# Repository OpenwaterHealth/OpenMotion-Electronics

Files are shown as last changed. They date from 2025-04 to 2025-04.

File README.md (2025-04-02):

# OpenMotion-Electronics
This repository contains the electrical layout files for all of the PCBs required for OpenMotion

# Overview
Electrical files for OpenMotion will be uploaded when major releases occur.

OpenMotion is still in development and files here represent prototypes for the three PCBAs required for OpenMotion. Those are: the console board, the camera aggregator board, and the camera sensor board. Eight camera sensor boards connect to a single camera aggregator board. Each aggregator connects to the console board via a 10 pin cable. Two aggregator boards (more broadly, sensor modules), may be connected to the console at a time. The console contains power conditioning electronics, laser control electronics, and components for connecting the two aggregator boards to the host PC. A power supply provides 12V to the Console Board. The console board connects to the host via USB Type-C.

Please see the other repositories in this organization for the Mechanical and Software files.

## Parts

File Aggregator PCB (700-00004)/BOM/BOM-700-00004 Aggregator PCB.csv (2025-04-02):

Line # | Name | Description | Designator | Revision ID | Revision Status | Quantity | TargetPrice | JLCPCB Part # | Manufacturer 1 | Manufacturer Part Number 1 | Manufacturer Lifecycle 1 | Supplier 1 | Supplier Part Number 1 | Supplier Unit Price 1 | Supplier Subtotal 1
 | 100nf | Cap Ceramic 100nF 10V X7R ±10% SMD 0402 +125°C Paper T/R | C6, C23, C24, C25, C26, C28, C34, C35, C36, C39 | CMP-13271-001069-1 | Up to date | 10 | 0 | C133086 | Samsung | CL05B104KP5NNNC | Volume Production | Digikey | 1276-1002-6-ND | 0.004 | 0.4
 | 2.2uF | CAP CER 2.2UF 10V X5R 0402 | C31, C32, C37 | CMP-03422-000618-1 | Up to date | 3 | 0 | C326606 | Yageo | CC0402KRX5R6BB225 | Volume Production | Digikey | 311-1686-1-ND | 0.053 | 1.59
 | BM10B-SURS-TF(LF)(SN) | CONN HEADER SMD 10POS 0.8MM | J9 | CMP-17439-000608-1 | Up to date | 1 | 0 | C5306166 | JST | BM10B-SURS-TF(LF)(SN) | Unknown
 | U.FL-R-SMT(10) | Ultra Small Surface Mount Coaxial Connector, 50 Ohm, -40 to 90 degC, 3-Pin SMD, RoHS, Tape and Reel | SYNC | CMP-002-00035-2 | Up to date | 1 | 0 | C5137195 | Hirose | U.FL-R-SMT(10) | Volume Production | Digikey | H9161DKR-ND | 0.975 | 9.75
 | QBLP595-IG | Chip LED 0402, Green, 0.02 A, 3.1 to 3.7 V, -40 to 80 degC, 2-Pin SMD, RoHS, Tape and Reel | V3 | CMP-007-00041-3 | Up to date | 1 | 0 | C264408 | QT-Brightek | QBLP595-IG | Unknown | Digikey | 1516-1216-6-ND | 0.181 | 1.81
 | QBLP595-R | Chip LED 0402, Red, 0.02 A, 2.0 to 2.5 V, -40 to 80 degC, 2-Pin SMD, RoHS, Tape and Reel | ERR | CMP-007-00040-3 | Up to date | 1 | 0 | C71911 | QT-Brightek | QBLP595-R | Unknown | Digikey | 1516-1217-6-ND | 0.167 | 1.67
 | 27K |  | R1 | CMP-2002-07025-1 | Up to date | 1 | 0 | C138022 | Yageo | RC0402FR-0727KL | Volume Production | Digikey | 311-27.0KLRCT-ND | 0.008 | 0.08
 | 10K |  | R2, R4, R5, R24, R25, R26, R36, R38 | CMP-2002-07353-1 | Up to date | 8 | 0 | C60490 | Yageo | RC0402FR-0710KL | Volume Production | Digikey | 311-10.0KLRDKR-ND | 0.0081 | 0.81
 | 56K |  | R3 | CMP-1011-00708-2 | Up to date | 1 | 0 | C114756 | Yageo | RC0402FR-0756KL | Volume Production | Digikey | 311-56.0KLRCT-ND | 0.007 | 0.07
 | 2.2K |  | R8, R9, R10, R11, R12, R13, R14, R15, R16, R17, R18, R19, R20, R21, R22, R23 | CMP-2002-07567-1 | Up to date | 16 | 0 | C114762 | Yageo | RC0402FR-072K2L | Volume Production | Digikey | 311-2.20KLRDKR-ND | 0.0071 | 1.136
 | 270 |  | R33, R34 | CMP-2002-07003-1 | Up to date | 2 | 0 | C163474 | Yageo | RC0402FR-07270RL | Volume Production | Digikey | 311-270LRDKR-ND | 0.007 | 0.14
 | ST1L05BPUR | Very Low Quiescent BiCMOS Voltage Regulator, Adjustable Vo, 6-Pin VFDFPN, Tape and Reel | U1 | CMP-0244-00292-1 | Up to date | 1 | 0 | C155640 | STMicroelectronics | ST1L05BPUR | Volume Production | Digikey | 497-6829-1-ND | 0.731 | 7.31
 | ST1L05CPU33R | Very Low Quiescent BiCMOS Voltage Regulator, 3.3V, 6-Pin VFDFPN, Tape and Reel | U3, U6 | CMP-0244-00293-1 | Up to date | 2 | 0 | C2969933 | STMicroelectronics | ST1L05CPU33R | Volume Production | Digikey | 497-10617-1-ND | 0.731 | 14.62
 | ICM-20948 | World’s Lowest Power 9-Axis MEMS MotionTracking(TM) Device, 1.71 to 3.6 V, -40 to 85 degC, 24-Pin QFN, RoHS, Tape and Reel | U5 | CMP-2000-07532-1 | Up to date | 1 | 0 | C726001 | TDK | ICM-20948 | Unknown
 | 5.1k |  | R31, R32 | CMP-2002-07753-1 | Up to date | 2 | 0 | C105872 | Yageo | RC0402FR-075K1L | Volume Production | Digikey | 311-5.10KLRDKR-ND | 0.008 | 0.16
 | 4.7uF | CAP CER 4.7UF 10V X5R 0402 | C1, C2, C3, C4, C10, C11, C12, C13, C14, C15, C16, C17, C18, C19, C27, C30 | CMP-2000-05997-2 | Up to date | 16 | 0 | C82864 | TDK | C1005X5R1A475K050BC | Volume Production | Digikey | 445-13820-6-ND | 0.098 | 15.68
 | 100nF | Chip Multilayer Ceramic Capacitors for General Purpose, 0402, 0.10uF, X7R, 15%, 10%, 50V | C5, C8, C9 | CMP-2008-04639-2 | Up to date | 3 | 0 | C77020 | Murata | GRM155R71H104KE14D | Volume Production | Digikey | 490-10700-6-ND | 0.023 | 0.69
 | Capacitor 1 uF +/- 10% 6.3 V 0402 | Chip Capacitor, 1 uF, +/- 10%, 6.3 V, 0402 (1005 Metric) | C7, C29, C33, C38 | CMP-001-00008-6 | Up to date | 4 | 0 | C14445 | Kyocera AVX | 04026D105KAT2A | Volume Production | Digikey | 478-KGM05AR50J105KHCT-ND | 0.017 | 0.68
 | 6pF | Multi-Layer Ceramic Capacitor 6pF C0G ±0.25pF 0402 Paper T/R | C21, C22 | CMP-2008-03869-2 | Up to date | 2 | 0 | C161330 | Murata | GJM1555C1H6R0CB01D | Volume Production | Digikey | 490-3104-1-ND | 0.036 | 0.72
 | 1-2328702-0 | No Description Available | J1, J2, J3, J4, J5, J6, J7, J8 |  |  | 8 | 0 | C3167956
 | 2.2k |  | R6, R7 | CMP-2002-07517-1 | Up to date | 2 | 0 | C82868 | Yageo | RC0402FR-0722KL | Volume Production
 | 8.06K |  | R37 | CMP-2002-07081-1 | Up to date | 1 | 0 | C276278 | Yageo | RC0402FR-078K06L | Volume Production | Digikey | 311-8.06KLRDKR-ND | 0.008 | 0.08
 | STM32H743VIH6 | HIGH-PERFORMANCE AND DSP WITH DP | U2 | CMP-12105-000020-1 | Up to date | 1 | 0 | C964146 | STMicroelectronics | STM32H743VIH6 | Volume Production | Digikey | 497-STM32H743VIH6-ND | 12.814 | 128.14
 | TCA9548ARGERQ1 | IC BUS SWITCH 1 X 8:1 24VQFN | U4 | CMP-04892-000080-1 | Up to date | 1 | 0 | C2674697 | Texas Instruments | TCA9548ARGERQ1 | Volume Production | Digikey | 296-TCA9548ARGERQ1CT-ND | 1.537 | 15.37
 | USB3320C-EZK-TR | IC TRANSCEIVER HALF 1/1 32QFN | U7 | CMP-0186-00336-2 | Up to date | 1 | 0 | C132156 | Microchip | USB3320C-EZK-TR | Volume Production | Digikey | USB3320C-EZK-DKR-ND | 2.17 | 21.7
 | 24MHz | CRYSTAL 24.0000MHZ 6PF SMD | Y1 | CMP-06054-000017-1 | Up to date | 1 | 0 | C127895 | Murata | XRCGB24M000F3M00R0 | Volume Production | Digikey | 490-5576-1-ND | 0.269 | 2.69
 | EVP-AWED4A | Tactile Switch SPST-NO Top Actuated Surface Mount | RST | CMP-050-000000-1 | Up to date | 1 | 0 | C585166
 | Resistor 4K7 +/-1 % 0402 63 mW | Chip Resistor, 4,7 kOhms, +/-1 %, 63 mW, -55 to 155 degC, 0402 | R27, R28, R29, R30, R35, R39, R40, R41 | CMP-009-00158-3 | Up to date | 8 | 0 | C25900 | Bourns | CR0402-FX-4701GLF | Volume Production | Digikey | CR0402-FX-4701GLFDKR-ND | 0.0063 | 0.63
 | SN74LV1T125DBVR | Single Power Supply, Single BUFFER GATE w/ 3-State Output (active low enable), DBV0005A, LARGE T&R | U8, U9 | CMP-0859-00122-3 | Up to date | 2 | 0 | C473338 | Texas Instruments | SN74LV1T125DBVR | Volume Production | Digikey | 296-37172-6-ND | 0.265 | 5.3

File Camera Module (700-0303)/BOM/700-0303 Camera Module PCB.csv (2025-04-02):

Line # | Name | Description | Designator | Revision Status | Quantity | Footprint | Manufacturer 1 | Manufacturer Part Number 1 | Manufacturer Lifecycle 1 | Supplier 1 | Supplier Part Number 1 | Supplier Subtotal 1
 | 4.7uF | Capacitor,4.7µF ±10% 6.3V Ceramic Capacitor X5R 0201 (0603 Metric) | C1 |  | 1 | CAP_CC0201_YAG
 | 1uF | Capacitor,1 µF ±10% 6.3V Ceramic Capacitor X5R 0201 (0603 Metric) | C2, C3, C4, C5, C6, C9, C10 |  | 7 | CAP_CC0201_YAG
 | 0.1uF | CAP,0.1µF ±10% 6.3V Ceramic Capacitor X5R 0201 (0603 Metric) | C7, C11, C12, C17, C18, C19, C20, C21 |  | 8 | CAP_CC0201_YAG
 | 2.2uF | CAP,2.2µF ±10% 6.3V Ceramic Capacitor X5R 0201 (0603 Metric) | C8, C13, C14, C15, C16 |  | 5 | CAP_CC0201_YAG
 | 10K | RES, 10 kOhms Â±1% 0.05W, 1/20W Chip Resistor 0201 _0603 Metric_ Thick Film | R1, R7 |  | 2 | RESC0603X28N
 | 20K | RES, 20 kOhms Â±1% 0.05W, 1/20W Chip Resistor 0201 _0603 Metric_ Thick Film | R2 |  | 1 | RESC0603X28N
 | 30K | RES, 30 kOhms Â±1% 0.05W, 1/20W Chip Resistor 0201 _0603 Metric_ Thick Film | R3 |  | 1 | RESC0603X28N
 | DNP | RES, 100 kOhms Â±1% 0.05W, 1/20W Chip Resistor 0201 _0603 Metric_ Thick Film | R6 |  | 1 | RESC0603X28N
 | 100K | RES, 100 kOhms Â±1% 0.05W, 1/20W Chip Resistor 0201 _0603 Metric_ Thick Film | R8 |  | 1 | RESC0603X28N
 | MIC5335-JGYMT-TR | IC, Linear Voltage Regulator IC Positive Fixed 2 Output 300mA, 300mA 6-TMLF® (1.6x1.6) | U1 |  | 1 | TMLF-6_MT_MCH
 | LIF-MD6000-6UWG36ITR | IC, FPGA - Field Programmable Gate Array Crosslink Interface MIPI D-Phy Bridge | U2 |  | 1 | BGA36N40P6X6_248X254X57N
 | 0X02C1B | IC, Camersa Sensor | U3 |  | 1 | OV_CSP-56
 | NCP156ABFCT120280T2G | IC, LDO Voltage Regulators DUAL 500 MA / 250 M A LDO | U4 |  | 1 | NCP156
 | 10K | RES, 10 kOhms Â±1% 0.05W, 1/20W Chip Resistor 0201 _0603 Metric_ Thick Film | R9 |  | 1 | RESC0603X28N
 | ECS-1618-480-BN-TR | 48MHz XO (Standard) CMOS Oscillator 1.8V Enable/Disable 4-SMD, No Lead | Y1 |  | 1 | OSC_ECS-1633-480-BN-TR
 | flex tail | Connector,10 Position FFC, FPC Connector Contacts, Bottom 0.020" (0.50mm) Surface Mount, Right Angle | J1 |  | 1 | flex tail
 | DNP | RES, 10 kOhms Â±1% 0.05W, 1/20W Chip Resistor 0201 _0603 Metric_ Thick Film | R10 |  | 1 | RESC0603X28N

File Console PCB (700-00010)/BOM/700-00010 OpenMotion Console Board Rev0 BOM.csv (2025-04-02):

Line # | Name | Description | Designator | Revision Status | Quantity | Footprint | Manufacturer 1 | Manufacturer Part Number 1 | Manufacturer Lifecycle 1 | Supplier 1 | Supplier Part Number 1 | Supplier Subtotal 1
 | 4.7uF | Capacitor, 4.7 µF ±10% 35V Ceramic Capacitor X5R 0805 (2012 Metric) | C53, C57 |  | 2 | CAPC2012X135N
 | 47uF | Capacitor,47 µF ±10% 16V Ceramic Capacitor X5R 1210 (3225 Metric) | C21, C23, C24, C27, C28, C34, C36, C360, C361, C362, C369, C370, C371, C372, C373, C374, C375 |  | 17 | CAP_CL32_SAM
 | 22uF | Capacitor, 22 µF ±20% 10V Ceramic Capacitor X5R 0805 (2012 Metric) | C178, C184, C193, C402, C408, C417, C458, C464, C473 |  | 9 | CAPC2012X140N
 | 0.1uF | CAP, 0.1 µF ±10% 25V Ceramic Capacitor X5R 0402 (1005 Metric) | C8, C11, C13, C14, C16, C22, C25, C30, C31, C32, C33, C35, C38, C39, C47, C48, C55, C61, C63, C65, C80, C88, C90, C91, C95, C96, C97, C100, C103, C104, C106, C108, C112, C130, C131, C132, C134, C137, C141, C142, C143, C146, C147, C158, C160, C161, C162, C163, C164, C167, C168, C173, C175, C179, C182, C183, C185, C187, C191, C192, C195, C196, C200, C202, C205, C207, C208, C210, C215, C218, C220, C221, C223, C229, C230, C232, C233, C234, C235, C237, C238, C239, C240, C242, C243, C244, C245, C246, C249, C250, C251, C252, C286, C310, C313, C315, C316, C317, C319, C320, C321, C322, C324, C326, C329, C330, C332, C334, C339, C342, C343, C344, C345, C346, C350, C355, C359, C366, C376, C381, C383, C391, C392, C397, C398, C399, C403, C406, C407, C409, C411, C415, C416, C419, C420, C437, C438, C443, C447, C448, C453, C455, C459, C462, C463, C465, C467, C471, C472, C475, C477, C480, C481, C525, C528, C532, C533, C534, C535, C536, C537, C538, C539, C540, C541, C542, C544, C545, C546, C547, C549, C550, C553, C554, C555, C556, C558 |  | 177 | G-155_MUR
 | 1uF | CAP, 1µF ±10% 25V Ceramic Capacitor X5R 0402 (1005 Metric) | C20, C43, C52, C85, C99, C109, C111, C204, C384, C504, C510, C513, C515 |  | 13 | G-155_MUR
 | 22uF | CAP, 22 µF ±20% 25V Ceramic Capacitor X5S 0603 (1608 Metric | C180, C189, C198, C404, C413, C422, C460, C469, C478 |  | 9 | CAPC17795_95N_KEM
 | 10uF | CAP, 10 µF ±20% 16V Ceramic Capacitor X5R 0603 (1608 Metric) | C113, C118, C120, C122, C172, C209, C211, C222, C224, C231, C236, C248, C314, C318, C358, C516, C529, C530, C531, C543, C548, C551 |  | 22 | CAP_GRM188_MUR
 | 0.1uF | CAP, 0.1 µF ±10% 25V Ceramic Capacitor X5R 0402 (1005 Metric) | C58, C72, C107, C385, C386 |  | 5 | G-155_MUR
 | 0.1uF | CAP, 0.1upF ±10% 200V Ceramic Capacitor X7R 0603 (1608 Metric) | C156 |  | 1 | CAPC17795_95N_KEM
 | 4.7uF | CAP, 4.7 µF ±20% 16V Ceramic Capacitor X5R 0402 (1005 Metric) | C102 |  | 1 | CAP_CC0402_YAG | Murata | GRM155R62A104ME14D | Volume Production | Arrow Electronics | GRM155R62A104ME14D | 74
 | APT1608SURCK | LED, Red 630nm LED Indication - Discrete 1.95V 0603 (1608 Metric) | D1, D5, D17 |  | 3 | LED_APT1608_KNB
 | GRN | LED, Green 570nm LED Indication - Discrete 2V 0402 (1005 Metric) | D14, D19, D20, D21, D44, D45, D55, D62, D63, D64 |  | 10 | FP-SML-P11MTT86R_0402-MFG
 | VLMO1500-GS08 | LED, Blue 470nm LED Indication - Discrete 2.7V 0402 (1005 Metric) | D13, D18 |  | 2 | FP-SML-P11MTT86R_0402-MFG
 | 5.5A TRIP | FUSE, Polymeric PTC Resettable Fuse 24V 3.3 A Ih Surface Mount 2920 (7351 Metric), Concave | F2 |  | 1 | 0ZCF0330FF2C_BEL
 | 25 Ohm @ 6A | Ferrite Bead, 25 Ohms @ 100 MHz 1 Power Line Ferrite Bead 0805 (2012 Metric) 6A 4mOhm | FB2, FB17 |  | 2 | IND_FBMJ-08052012_TAY
 | 30 Ohms 3A | Ferrite Bead, 30 Ohms 1 Signal Line Ferrite Bead 0603 (1608 Metric) 3A 40mOhm | FB1, FB3, FB4, FB5, FB6, FB7, FB8, FB9, FB10, FB11, FB12, FB13, FB14, FB15, FB16, FB18, FB19, FB20, FB21, FB22, FB23, FB24, FB25, FB26, FB27, FB28, FB33, FB34, FB35, FB36, FB37, FB39, FB57, FB58, FB59, FB60 |  | 36 | WE-CBF-0603
 | 120 Ohm | Ferrite Bead , 120 Ohms 1 Power Line 0402 (1005 Metric) 2A 55mOhm | FB31, FB32, FB45, FB46, FB51, FB52, FB53, FB54, FB55 |  | 9 | IND_BLM15_0402_MUR
 | CSD15380F3T | MOSFET, 20-V N-Channel FemtoFET MOSFET 3-PICOSTAR -55 to 150 | Q13, Q15 |  | 2 | TRXDFN69X60X35-3N
 | 10K | Resistor, 10K Ohms ±1% 0.063W, 1/16W Chip Resistor 0402 (1005 Metric) Moisture Resistant Thick Film | R2, R44, R95, R112, R115, R116, R118, R121, R125, R128, R129, R131, R134, R141, R150, R151, R152, R170, R214 |  | 19 | RC0402N_YAG
 | 4.7K | Resistor, 4.7K Ohms ±1% 0.063W, 1/16W Chip Resistor 0402 (1005 Metric) Moisture Resistant Thick Film | R40, R41, R142, R143, R165, R166 |  | 6 | RC0402N_YAG
 | 10K | RES, 10K ±1% 0.063W, 1/16W Chip Resistor 0402 (1005 Metric) Thick Film | R299, R308 |  | 2 | BO_CR0402
 | 10K Ohm | Resistor, 10K Ohms ±1% 0.063W, 1/16W Chip Resistor 0402 (1005 Metric) Moisture Resistant Thick Film | R3, R31, R35, R49, R85, R100, R113, R326, R328, R342, R344 |  | 11 | RC0402N_YAG
 | 29.4K | Resistor, 29.4 kOhms ±1% 0.063W, 1/16W Chip Resistor 0402 (1005 Metric) Automotive AEC-Q200 Thick Film | R13 |  | 1 | STA_RMCF0402_STP
 | 35mOhm | Resistor, 35 mOhms ±1% 1W Chip Resistor 2512 (6432 Metric) Automotive AEC-Q200, Current Sense, Moisture Resistant Metal Element | R271, R283 |  | 2 | RESC6432X80N
 | 10K Ohm | Resistor, 10K Ohms ±1% 0.063W, 1/16W Chip Resistor 0402 (1005 Metric) Moisture Resistant Thick Film | R5, R6, R15, R28, R34, R68, R70, R80, R83, R88, R89, R97, R103, R108, R110, R242, R249, R261, R265, R293, R302 |  | 21 | RC0402N_YAG
 | 86.6K | Resistor, 86.6 kOhms ±0.1% 0.063W, 1/16W Chip Resistor 0402 (1005 Metric) Automotive AEC-Q200 Thin Film | R55, R106, R206, R250, R296, R305 |  | 6 | 0402 | Yageo | RT0402FRE07100RL | Volume Production | Future Electronics | 4303467 | 29
 | 4.99K | Resistor,4.99 kOhms ±1% 0.1W, 1/10W Chip Resistor 0402 (1005 Metric) Automotive AEC-Q200 Thick Film | R58, R332, R350 |  | 3 | RC0402N_PAN
 | 24K | Resistor, 24 kOhms ±1% 0.063W, 1/16W Chip Resistor 0402 (1005 Metric) Thick Film | R56 |  | 1 | RESC1005X35N
 | 31.6K | Resistor, 31.6K Ohms ±1% 0.063W, 1/16W Chip Resistor 0402 (1005 Metric) Moisture Resistant Thick Film | R298, R307 |  | 2 | RC0402N_YAG
 | 49.9 | Resistor, 49.9 Ohms ±1% 0.063W, 1/16W Chip Resistor 0402 (1005 Metric) Moisture Resistant Thick Film | R17, R21, R76, R92, R98, R99, R203, R204, R205 |  | 9 | RC0402N_YAG
 | 24.9 | Resistor, 24.9 Ohms ±1% 0.063W, 1/16W Chip Resistor 0402 (1005 Metric) Automotive AEC-Q200 Thick Film | R36, R62, R75, R77, R94 |  | 5 | RES_CRCW_0402
 | 1.8K | Resistor, 1.8K Ohms ±1% 0.063W, 1/16W Chip Resistor 0402 (1005 Metric) Moisture Resistant Thick Film | R90 |  | 1 | RC0402N_YAG
 | 5003 | Test Point, Orange, Height 4.6 mm, Tail Length 3 mm, 1-Pin THD, RoHS | TP1, TP2, TP3, TP4, TP5, TP6, TP7, TP11, TP12, TP13, TP14, TP15, TP16, TP17, TP18, TP19, TP20, TP21, TP22, TP23, TP24, TP25, TP26, TP27, TP28, TP29, TP32, TP33, TP35, TP36, TP39, TP40 |  | 32 | KSTN-5003
 | MIC29502WU-TR | IC, Linear Voltage Regulator IC Positive Adjustable 1 Output 5A TO-263-5 | U82, U83 |  | 2 | TO-263-5_MCH
 | LTM8074EY#PBF | IC, Non-Isolated PoL Module DC DC Converter 1 Output 0.8 ~ 12V 1.2A 3.2V - 40V Input | U3, U28, U73 |  | 3 | 05-08-1566_ADI
 | LT1965IDD#PBF | IC, Linear Voltage Regulator IC Positive Adjustable 1 Output 1.1A 8-DFN (3x3) | U86, U92 |  | 2 | DFN-8_DD_LIT
 | MAX31875R2TZS+T | IC,Temperature Sensor Digital, Local -40°C ~ 125°C 12 b 4-WLP (0.84x0.84) | U13, U48, U51 |  | 3 | 21-100151A_Z40C0+2_MXM
 | LTC1440IDDPBF | Comparator with Voltage Reference CMOS, TTL 8-DFN (3x3) | U32 |  | 1 | DFN-8_DD_LIT
 | 0.01uF | CAP, 0.01 µF ±10% 50V Ceramic Capacitor X5R 0402 (1005 Metric) | C1, C492, C493, C505, C508 |  | 5 | G-155_MUR
 | 0.1uF | CAP, 0.1 µF ±10% 25V Ceramic Capacitor X5R 0402 (1005 Metric) | C2, C41, C46, C50, C51, C54, C66, C67, C68, C69, C71, C77, C82, C83, C93, C105, C117, C119, C121, C123, C124, C125, C165, C255, C258, C263, C264, C265, C266, C267, C268, C269, C270, C271, C272, C273, C274, C275, C279, C280, C283, C284, C285, C288, C289, C290, C291, C292, C293, C297, C305, C306, C308, C425, C426, C427, C428, C434, C435, C454, C518, C526, C552, C557, C559 |  | 65 | G-155_MUR
 | 470pF | Capacitor, 470 pF ±5% 100V Ceramic Capacitor C0G, NP0 0603 (1608 Metric) | C3, C6 |  | 2 | CAPC17595_87N_KEM
 | 47uF | Capacitor, 47 µF ±20% 25V Ceramic Capacitor X5R 1206 (3216 Metric) | C4, C5, C12, C15, C26, C29, C133, C253, C254, C301, C307, C311, C347, C348, C349, C351, C356, C357 |  | 18 | CAP_3216_TDK
 | 1uF | CAP, 1µF ±10% 25V Ceramic Capacitor X5R 0402 (1005 Metric) | C7, C9, C92, C94, C101, C138, C139, C140, C148, C149, C151, C152, C153, C155, C261, C277, C298, C491, C495, C498, C500, C523 |  | 22 | G-155_MUR
 | 22uF | CAP, 22 µF ±20% 25V Ceramic Capacitor X5S 0603 (1608 Metric | C10, C70, C423, C424 |  | 4 | CAPC17795_95N_KEM
 | 47uF | Capacitor, 47 µF ±20% 25V Ceramic Capacitor X5R 1206 (3216 Metric) | C17, C18, C19, C37, C40, C42, C44, C45, C56, C59, C62, C64, C75, C76, C78, C79, C81, C84, C114, C115, C116, C126, C127, C128, C129, C135, C136, C166, C169, C170, C171, C176, C177, C181, C186, C188, C190, C194, C197, C199, C302, C303, C304, C323, C325, C327, C328, C331, C335, C336, C340, C341, C352, C353, C354, C363, C364, C365, C377, C378, C379, C380, C388, C389, C390, C393, C394, C395, C396, C400, C401, C405, C410, C412, C414, C418, C421, C436, C439, C440, C441, C442, C444, C445, C446, C449, C450, C451, C452, C456, C457, C461, C466, C468, C470, C474, C476, C479 |  | 98 | CAP_GRM31CR_MUR
 | 10uF | CAP, 10 µF ±20% 16V Ceramic Capacitor X5R 0603 (1608 Metric) | C49, C110, C144, C145, C387, C490, C496, C497, C499, C503, C506, C507, C511, C512, C514 |  | 15 | CAP_GRM188_MUR
 | 4.7uF | CAP, 4.7 µF ±20% 10V Ceramic Capacitor X5R 0402 (1005 Metric) | C60, C86, C87, C89, C154, C157, C382, C522 |  | 8 | G-155_MUR | Murata | GRM155R62A104ME14D | Volume Production | Arrow Electronics | GRM155R62A104ME14D | 74
 | 47uF | Capacitor,47 µF ±10% 16V Ceramic Capacitor X5R 1210 (3225 Metric) | C73, C74 |  | 2 | CAP_CL32_SAM
 | 5pF | CAP, 5 pF ±0.1pF 50V Ceramic Capacitor C0G, NP0 0402 (1005 Metric) | C98 |  | 1 | CC0402N_YAG | Murata | GJM1555C1H5R0BB01D | Volume Production | Digikey | 490-8103-1-ND | 0.14
 | 10pF | CAP, 10pF ±0.25pF 50V Ceramic Capacitor C0G, NP0 0402 (1005 Metric) | C201, C203, C206, C214, C216, C217, C219, C487, C488, C489, C494, C501, C502, C509, C524 |  | 15 | G-155_MUR | Murata | GRM155R62A104ME14D | Volume Production | Arrow Electronics | GRM155R62A104ME14D | 74
 | 0.1uF | CAP, 0.1 µF ±10% 25V Ceramic Capacitor X5R 0402 (1005 Metric) | C212, C225 |  | 2 | G-155_MUR
 | 4.7uF | Capacitor, 4.7 µF ±20% 16V Ceramic Capacitor X5R 0402 (1005 Metric) | C213, C226 |  | 2 | CAP_0402E_AVX
 | 10SVP47M | Conductive Polymer Aluminum Solid Capacitors (OS-CON) 47uF ±20% 10V | C256, C257 | Up to date | 2 | FP-OS-CON-SMT-C6-MFG | Panasonic | 10SVP47M | Volume Production | Farnell | 2354675 | 1.08041
 | 2.2uF | CAP, 2.2 µF ±20% 25V Ceramic Capacitor X5R 0402 (1005 Metric) | C259, C260 |  | 2 | G-155_MUR
 | 10uF | CAP, 10 µF ±20% 16V Ceramic Capacitor X5R 0603 (1608 Metric) | C262, C287 |  | 2 | CAP_GRM188_MUR
 | 120uF | Molded Tantalum Polymer Capacitor 120uF 20% 6.3V life 1000Hours SMD 1411 | C276, C278 |  | 2 | FP-POSCAP-B2-MFG
 | 6pF | Capcitor 6 pF ±0.25pF 50V Ceramic Capacitor C0G, NP0 0402 (1005 Metric) | C281, C282, C295, C296 |  | 4 | G-155_MUR | Murata | GRM1555C1H6R0CA01D | Not Recommended for New Design | Mouser | 81-GRM1555C1H6R0CA1D | 0.26
 | 1nF | CAP, 1000 pF ±5% 50V Ceramic Capacitor C0G, NP0 0603 (1608 Metric) | C294 |  | 1 | CAPC17795_95N_KEM
 | GRM188R61E106MA73D | CAP, CERM, 10 µF, 25 V, +/- 20%, X5R, 0603 | C299, C300 |  | 2 | 0603 | Murata | GRM188R61E106MA73D | Volume Production | Digikey | 490-7202-1-ND | 0.52
 | 4.7uF | CAP, 4.7 µF ±20% 16V Ceramic Capacitor X5R 0402 (1005 Metric) | C312 |  | 1 | CAP_CC0402_YAG | Murata | GRM155R62A104ME14D | Volume Production | Arrow Electronics | GRM155R62A104ME14D | 74
 | 4700pF | Capacitor 4700 pF ±10% 25V Ceramic Capacitor X7R 0402 (1005 Metric) | C333 |  | 1 | CC0402N_YAG
 | 22pF | Capacitor 22 pF ±5% 25V Ceramic Capacitor C0G, NP0 0402 (1005 Metric) | C337 |  | 1 | CAPC10555_55N_KEM
 | 10uF | CAP, 0.1 µF ±10% 25V Ceramic Capacitor X5R 0402 (1005 Metric) | C338 |  | 1 | G-155_MUR
 | 0.1uF 50V | CAP CER 0.1UF 50V X7R 0603 | C367, C368, C482, C483, C484, C485, C486 |  | 7 | CAPC1608X09N |  |  |  | Digi-Key | 399-C0603C104K5RAC7867DKR-ND
 | 82uF | Capacitor, 82 µF 25 V Aluminum - Polymer Capacitors Radial, Can - SMD 25mOhm 1000 Hrs @ 125°C | C429, C430, C431, C432, C433 |  | 5 | CAP_25SVPK82M
 | 0.1uF | Capacitor 0.1 µF ±10% 25V Ceramic Capacitor X5R 0603 (1608 Metric) | C517, C519, C520, C521 |  | 4 | CAP_0603_X_WAL
 | SMD110PL-TP | Diode 100 V 1A Surface Mount SOD-123FL | CR1, CR2 |  | 2 | SOD-123FL_MCC | MCC | SMD110PL-TP | Volume Production | Digikey | SMD110PL-TPMSCT-ND | 0.36
 | ESD321DYAR | Diode 6.3V (Typ) Clamp 6A (8/20µs) Ipp Tvs Diode Surface Mount SOT-5X3 | CR3, CR4, CR5, CR6, CR7, CR8, CR9, CR10, CR11, CR12, CR13 |  | 11 | SOT5x3_DYA_TEX | Texas Instruments | ESD321DYAR | Unknown | Mouser | 595-ESD321DYAR | 0.451
 | B240A-E3/5AT | DIODE SCHOTTKY 40V 2A DO214AC | D2, D12 |  | 2 | DO-214AC UNIDIRECTIONAL | Vishay Semiconductors | B240A-E3/61T | Volume Production | Digikey | B240A-E3/61TGICT-ND | 0.76
 | 1N4148WX-TP | Diode, 75 V 150mA Surface Mount SOD-323 | D3, D15 |  | 2 | CR_SOD323_MCC
 | Green Vf 2.0 | LED GREEN 0603 SMD | D4, D10, D11, D22, D24, D48, D50, D51, D53, D56, D57 |  | 11 | LED0603_GREEN | Vishay Lite-On | LTST-C191KGKT | Volume Production | Digikey | 160-1446-1-ND | 1.1
 | B240A-E3/5AT | DIODE SCHOTTKY 40V 2A DO214AC | D6, D16, D43, D46, D47, D49, D52, D54, D58, D59, D60 |  | 11 | DO-214AC UNIDIRECTIONAL | Vishay Semiconductors | B240A-E3/61T | Volume Production | Digikey | B240A-E3/61TGICT-ND | 2.805
 | LTST-C191KSKT | LED Yellow 591nm LED Indication - Discrete 2.1V 0603 (1608 Metric) | D7 |  | 1 | LED_LTST-C191KRKT_LTO | Vishay Lite-On | LTST-C191KSKT | Volume Production | Digikey | 160-1448-1-ND | 0.15
 | LTST-C190KFKT | LED, Orange 605nm LED Indication - Discrete 2V 0603 (1608 Metric) | D8, D23 |  | 2 | LEDM1608X80 | Vishay Lite-On | LTSTC190KFKT | Unknown | Avnet | LTST-C190KFKT | 93.12
 | 60V 7A | DIODE SCHOTTKY 60V 7A POWERDI5 | D9 |  | 1 | Power DI 5 | Diodes | PDS760-13 | Volume Production | Digikey | PDS760DICT-ND | 1.05
 | 3.2V | Diode,Zener Diode 3.2 V 1 W ±6.67% Surface Mount PMDTM | D25, D26 |  | 2 | DIO_PDZVTFT_ROM
 | RED | LED, Red 630nm LED Indication - Discrete 1.95V 0603 (1608 Metric) | D27, D28, D30, D31, D34, D35, D36, D37 |  | 8 | LED_APT1608_KNB
 | BLUE | LED, Blue 470nm LED Indication - Discrete 3.2V 0603 (1608 Metric) | D29, D38 |  | 2 | LED_150060B_WRE
 | GRN | LED, Green 573nm LED Indication - Discrete 2V 0603 (1608 Metric) | D32, D33, D39, D40 |  | 4 | LED_150060B_WRE
 | TVS 24V | TVS DIODE 24VWM 38.9VC DO214AC | D41 |  | 1 | DO-214AC BIDIRECTIONAL | Littelfuse | SMAJ24CA | Volume Production | Digikey | SMAJ24CALFDKR-ND | 0.31
 | Green Vf 2.0 | LED GREEN 0603 SMD | D42 |  | 1 | LED0603_GREEN | Vishay Lite-On | LTST-C191KGKT | Volume Production | Digikey | 160-1446-1-ND | 0.15
 | 4.55V | Zener Diode 4.55 V 1 W ±5.81% Surface Mount PMDTM | D61 |  | 1 | DIO_PDZVTFT_ROM | Microchip | TCM810SVNB713 | Volume Production | Digikey | TCM810SVNB713CT-ND | 0.46
 | 5.5A TRIP | FUSE, Polymeric PTC Resettable Fuse 24V hold 3.3 A Ih Surface Mount 2920 (7351 Metric), Concave | F1 |  | 1 | 0ZCF0330FF2C_BEL
 | 0ZCG0050AF2C | FUSE, Polymeric PTC Resettable Fuse 30V 500 mA Ih Surface Mount 1812 (4532 Metric), Concave | F3 |  | 1 | 0ZCG_BEL
 | 47053-1000 | CONN HEADER VERT 4POS 2.54MM | FAN1, FAN2 | Up to date | 2 | FP-470531000-MFG | Molex | 47053-1000 | Volume Production | Avnet | 0470531000 | 0.62312
 | 600 Ohm | Ferrite Bead , 600 Ohms @ 100 MHz 0402 (1005 Metric) 300mA 520mOhm | FB29, FB30 |  | 2 | IND_BLM15_0402_MUR
 | 80 Ohms 1A | Ferrite Bead, 80 Ohms @ 100 MHz 1 Power Line Ferrite Bead 0402 (1005 Metric) 1A 100mOhm | FB38, FB40, FB41, FB42, FB43, FB44, FB47, FB48, FB49, FB50, FB56 |  | 11 | 0402
 | Fiducial | Fiducial mark. There is nothing to buy or mount. | FID1, FID2, FID3 |  | 3 | Fiducial10-20
 | BLE32PN300SN1L | Ferrite Bead, 30 Ohms @ 100MHz 1 Power Line Ferrite Bead 1210 _3225 Metric_ 10A 1.6mOhm | FL1, FL2 |  | 2 | BEADC3225X220N |  |  |  | Future Electronics | 2109477
 | T1M-05-GF-DV-K | Connector Header Surface Mount 10 position 0.039" (1.00mm) | J1, J2, J3, J4 |  | 4 | SAMTEC_T1M-05-X-DV |  |  |  | Avnet | T1M-05-GF-DV-K
 | T1M-02-F-SH-L-K | CONN HEADER SMD R/A 2POS 1MM | J5 |  | 1 | SAMTEC_T1M-02-F-SH-L-K
 | 61300411121 | 4 pins, 1 row, straight, gold plating | J6 |  | 1 | 61300411121
 | IPL1-104-01-L-D-RA | Connector Header Through Hole, Right Angle 8 position 0.100" (2.54mm) | J8 |  | 1 | SAMTEC_IPL1-104-01-L-D-RA
 | 0022232021 | CONN HEADER VERT 2POS 2.54MM | J9, J10, J11 |  | 3 | CONN_A-6373-02A_MOL
 | GSB1CA11101DSHR | USB2.0, Type C, Vertical, Height 6.40mm, Dual Row Surface Mount | J12 |  | 1 | AMPHENOL_GSB1CA11101DSHR
 | 10144041-10011LF | MinitekÂ®0.8mm, Wire to Board connector, R/ASMTHeader, 10Positions, Tin Plating, Cream Color, Halogen Free, Glow Wire Compatible | J13, J14 | Up to date | 2 | AMPHENOL_10144041-10011LF
 | 3.3uH | Inductor 3.3 µH Shielded Drum Core, Wirewound Inductor 3.5 A 20mOhm Max Nonstandard | L1 |  | 1 | IND_BOURNS_SRR6038
 | CMT908-H1 | CMT Series 2 mH 7.5 A 0.02 Ohm DCR Through Hole Vertical Common Mode Inductor | L2 |  | 1 | IND_CMT908-H1
 | ACM7060-701-2PL-TL01 | 2 Line Common Mode Choke Surface Mount 700 Ohms @ 100 MHz 4A DCR 15mOhm | L3, L4, L5, L6, L7, L8, L10, L11 |  | 8 | IND_ACM7060_TDK | TDK | ACM7060-701-2PL-TL01 | Volume Production | Digikey | 445-2215-1-ND | 11.36
 | 1kohm @ 100kHz 6A 14mOhm | CMC 6A 2LN 1K OHM SMD | L9 |  | 1 | Choke, ACM1211-102-2PL-TL01 | TDK | ACM1211-102-2PLTL01 | Unknown | Digikey | 445-2213-1-ND | 1.7
 | LTST-C235KGKRKT | LED, Green, Red 571nm Green, 631nm Red LED Indication - Discrete 2V Green, 2V Red 1206 (3216 Metric) | LED1, LED2, LED3 |  | 3 | LTST-C235KGKRKT_LTO
 | 577202B00000G | HEAT SINK TO-220 .500" COMPACT | MP1, MP2 |  | 2 | FP-577202B00000G-MFG
 | 61030621121 | Connector Header Surface Mount 6 position 0.100" (2.54mm) | P1 |  | 1 | 61030621121
 | BSS138W-7-F | N-Channel 50 V 200mA (Ta) 200mW (Ta) Surface Mount SOT-323 | Q1 |  | 1 | SOT-323_DIO
 | FSB560A | FSB560A Bipolar Transistors - BJT NPN Transistor Low Saturation | Q2, Q3, Q4 |  | 3 | FP-527AG-MFG | ON Semiconductor / Fairchild | FSB560A | Volume Production | Mouser | 512-FSB560A | 1.8
 | MMBT3904 | NPN General Purpose Amplifier, 40 V, 0.2 A, -55 to 150 degC, 3-Pin SOT23, RoHS, Tape and Reel | Q5, Q8 |  | 2 | FAIR-SOT23-3_V | ON Semiconductor / Fairchild | MMBT3904 | Obsolete | Farnell | 9846727 | 0.87881
 | BSZ15DC02KDHXTMA1 | IC Mosfet Array 20V 5.1A, 3.2A 2.5W Surface Mount PG-TSDSON-8-FL | Q21, Q22 |  | 2 | PG-TSDSON-8_INF
 | 562 | Resistor, 562 Ohms ±1% 0.063W, 1/16W Chip Resistor 0402 (1005 Metric) Moisture Resistant Thick Film | R1, R8, R10, R12, R19, R20, R81, R101, R111, R157, R289, R291 |  | 12 | RC0402N_YAG | Yageo | RC0402FR-07562RL | Volume Production | Future Electronics | 9531203 | 7
 | 510 | RES,510 Ohms ±5% 0.063W, 1/16W Chip Resistor 0402 (1005 Metric) Moisture Resistant Thick Film | R4, R7 |  | 2 | STA_RMCF0402_STP | Yageo | RC0402JR-07510RL | Volume Production | Digikey | 311-510JRCT-ND | 0.07
 | 25.5K | RES, 25.5 kOhms ±1% 0.063W, 1/16W Chip Resistor 0402 (1005 Metric) Automotive AEC-Q200 Thick Film | R9, R78 |  | 2 | STA_RMCF0402_STP
 | 16K | RES, 16 kOhms ±1% 0.063W, 1/16W Chip Resistor 0402 (1005 Metric) Moisture Resistant Thick Film | R11 |  | 1 | STA_RMCF0402_STP
 | 100K | Resistor, 100K Ohms ±1% 0.063W, 1/16W Chip Resistor 0402 (1005 Metric) Moisture Resistant Thick Film | R14, R57, R72, R79, R82, R84, R96, R102, R107, R178, R184, R185, R188, R189, R264 |  | 15 | RC0402N_YAG | Yageo | RC0402FR-07100KL | Volume Production | Future Electronics | 6468466 | 9
 | 10K | Resistor, 10kOhms ±1% 0.063W, 1/16W Chip Resistor 0402 (1005 Metric) Moisture Resistant Thick Film | R16, R18, R22, R23, R24, R32, R61, R174, R175, R176, R179, R180, R181, R198, R199, R286, R288, R290, R306, R309 |  | 20 | RC0402N_YAG | Samsung | RC1005F103CS | Volume Production | Digikey | 1276-3431-1-ND | 0.78
 | 330 | Resistor, 330 Ohms ±1% 0.063W, 1/16W Chip Resistor 0402 (1005 Metric) Moisture Resistant Thick Film | R25, R27 |  | 2 | RC0402N_YAG |  |  |  | Digikey | 311-330LRCT-ND
 | 49.9 | Resistor, 49.9 Ohms ±1% 0.063W, 1/16W Chip Resistor 0402 (1005 Metric) Moisture Resistant Thick Film | R26, R38, R53 |  | 3 | RC0402N_YAG
 | 4.99K | Resistor,4.99 kOhms ±1% 0.1W, 1/10W Chip Resistor 0402 (1005 Metric) Automotive AEC-Q200 Thick Film | R29, R74, R120 |  | 3 | RC0402N_PAN
 | 45.3K | RES, 45.3 kOhms ±1% 0.063W, 1/16W Chip Resistor 0402 (1005 Metric) Moisture Resistant Thick Film | R30 |  | 1 | STA_RMCF0402_STP
 | 5mOhm | Resistor 5 mOhms ±1% 1.5W Chip Resistor 2010 (5025 Metric) Current Sense, Moisture Resistant Metal Element | R33, R73, R109, R241, R262, R292, R301 |  | 7 | STA_CSNL2010>=3.1_STP | Stackpole Electronics | CSNL2010FT5L00 | Volume Production | Digikey | CSNL2010FT5L00CT-ND | 4.32
 | 3.32K | Resistor,3.32 kOhms ±1% 0.063W, 1/16W Chip Resistor 0402 (1005 Metric) Automotive AEC-Q200 Thick Film | R37 |  | 1 | STA_RMCF0402_STP
 | 3K | Resistor 3 kOhms ±0.1% 0.063W, 1/16W Chip Resistor 0402 (1005 Metric) Automotive AEC-Q200 Thin Film | R39, R42, R47, R48, R130, R133, R135, R158, R159, R207, R251, R253, R254, R255, R268, R269, R270, R273, R274, R275, R276, R277, R278, R279, R280, R281, R282, R356 |  | 28 | STA_RMCF0402_STP | Panasonic | ERA-2AEB302X | Volume Production | Mouser | 667-ERA-2AEB302X | 2.436
 | 1K | Resistor, 1K Ohms ±1% 0.063W, 1/16W Chip Resistor 0402 (1005 Metric) Moisture Resistant Thick Film | R43, R87, R93, R117, R122, R201, R202, R324, R325, R327, R329, R330, R333, R334, R336, R337, R338, R340, R341, R343, R345, R346, R348, R349, R352, R353, R354 |  | 27 | RC0402N_YAG
 | 69.8K | Resistor, 69.8K Ohms ±1% 0.063W, 1/16W Chip Resistor 0402 (1005 Metric) Moisture Resistant Thick Film | R45 |  | 1 | RC0402N_YAG | Yageo | RC0402FR-0769K8L | Volume Production | Future Electronics | 7900491 | 7
 | 60.4K | Resistor, 60.4 kOhms ±0.1% 0.063W, 1/16W Chip Resistor 0402 (1005 Metric) Automotive AEC-Q200 Thin Film | R46, R132, R304 |  | 3 | 0402_PAN
 | 0 ohm | Resistor, 0 Ohms Jumper Chip Resistor 0402 (1005 Metric) Automotive AEC-Q200 Thick Film | R50, R52 |  | 2 | RC0402N_PAN
 | 180 | RES, 180 Ohms ±1% 0.063W, 1/16W Chip Resistor 0402 (1005 Metric) Moisture Resistant Thick Film | R51 |  | 1 | STA_RMCF0402_STP | Yageo | RC0402FR-07180RL | Volume Production | Digikey | 311-180LRCT-ND | 0.1
 | 1K | Resistor, 1K Ohms ±1% 0.063W, 1/16W Chip Resistor 0402 (1005 Metric) Moisture Resistant Thick Film | R54, R63, R119, R126 |  | 4 | RC0402N_YAG
 | 60.4K | Resistor, 60.4 kOhms ±0.1% 0.063W, 1/16W Chip Resistor 0402 (1005 Metric) Automotive AEC-Q200 Thin Film | R59, R105 |  | 2 | 0402_PAN | Panasonic | ERA-2AEB6042X | Volume Production | Mouser | 667-ERA-2AEB6042X | 0.2
 | 24K | Resistor, 24 kOhms ±1% 0.063W, 1/16W Chip Resistor 0402 (1005 Metric) Thick Film | R60 |  | 1 | RESC1005X35N
 | 470 | RES, 470 Ohms ±1% 0.063W, 1/16W Chip Resistor 0402 (1005 Metric) Moisture Resistant Thick Film | R64, R104, R114 |  | 3 | 0402 | Yageo | RC0402FR-07470RL | Volume Production | Future Electronics | 9333527 | 7
 | 4.7K | Resistor 4.7 kOhms ±0.1% 0.063W, 1/16W Chip Resistor 0402 (1005 Metric) Automotive AEC-Q200, Moisture Resistant Metal Film | R65, R66, R123, R127, R136, R156, R171, R222, R238, R239, R240, R243, R245, R246, R247, R248, R252, R256, R257, R258, R259, R260, R263, R266 |  | 24 | RESC1005X40N | KOA Speer | RN73H1ETTP4701B25 | Volume Production | Digikey | 2019-RN73H1ETTP4701B25CT-ND | 3.192
 | 10mOhm | 10 mOhms ±1% 1W Chip Resistor 2010 (5025 Metric) Current Sense Thick Film | R67, R91 |  | 2 | STA_CSRN2010_STP | Stackpole Electronics | CSRN2010FK10L0 | Volume Production | Digikey | CSRN2010FK10L0CT-ND | 1.38
 | 20K | Resistor, 20 kOhms ±1% 0.1W, 1/10W Chip Resistor 0402 (1005 Metric) Automotive AEC-Q200 Thick FilmMoisture Resistant Thick Film | R69, R244 |  | 2 | RC0402N_PAN
 | 4.7K | Resistor, 4.7K Ohms ±1% 0.063W, 1/16W Chip Resistor 0402 (1005 Metric) Moisture Resistant Thick Film | R71, R155, R164, R190, R191, R192, R193, R195, R197, R200, R236, R294, R295, R297, R300, R303 |  | 16 | RC0402N_YAG
 | 330 | RES, 330 ±1% 0.063W, 1/16W Chip Resistor 0402 (1005 Metric) Automotive AEC-Q200 Thick Film | R86 |  | 1 | STA_RMCF0402_STP
 | 24.9 | Resistor, 24.9 Ohms ±1% 0.063W, 1/16W Chip Resistor 0402 (1005 Metric) Automotive AEC-Q200 Thick Film | R124, R137, R140, R162 |  | 4 | RES_CRCW_0402
 | DNP | Resistor, 0 Ohms ±1% 0.063W, 1/16W Chip Resistor 0402 (1005 Metric) Moisture Resistant Thick Film | R138, R139, R148, R149, R160, R161, R163 |  | 7 | RC0402N_YAG
 | 0 Ohm | Resistor, 0 Ohms ±1% 0.063W, 1/16W Chip Resistor 0402 (1005 Metric) Moisture Resistant Thick Film | R144, R145, R146, R147, R167, R168, R169 |  | 7 | RC0402N_YAG
 | 4.7K | Resistor, 4.7K Ohms ±1% 0.063W, 1/16W Chip Resistor 0402 (1005 Metric) Moisture Resistant Thick Film | R153, R154, R172, R173 |  | 4 | RC0402N_YAG
 | CRCW0402330RFKED | RES, 330, 1%, 0.063 W, AEC-Q200 Grade 0, 0402 | R177 |  | 1 | 0402 |  |  |  | Digi-Key
 | 1K | Resistor 1 kOhms ±1% 0.063W, 1/16W Chip Resistor 0402 (1005 Metric) Automotive AEC-Q200, Moisture Resistant Metal Film | R182, R183, R229 |  | 3 | RESC1005X40N
 | 90.9K | RES, 90.9 kOhms ±1% 0.063W, 1/16W Chip Resistor 0402 (1005 Metric) Moisture Resistant Thick Film | R186, R310 |  | 2 | 0402 | Panasonic | ERJ-2RKF2401X | Volume Production | Digikey | P2.40KLCT-ND | 0.2
 | 12K | Resistor, 12K Ohms ±1% 0.063W, 1/16W Chip Resistor 0402 (1005 Metric) Moisture Resistant Thick Film | R187 |  | 1 | RC0402N_YAG | Yageo | RC0402JR-0712KL | Volume Production | Future Electronics | 6771661 | 6
 | 27.4K | RES, 27.4K Ohms ±1% 0.063W, 1/16W Chip Resistor 0402 (1005 Metric) Moisture Resistant Thick Film | R194, R196 |  | 2 | STA_RMCF0402_STP | Yageo | RC0402FR-0727K4L | Volume Production | Avnet | 49AK1380 | 0.2
 | 1K | Resistor, 1K Ohms ±1% 0.063W, 1/16W Chip Resistor 0402 (1005 Metric) Moisture Resistant Thick Film | R208, R209, R210, R211, R212 |  | 5 | RC0402N_YAG
 | 100 Ohm | Resistor, 100 Ohms ±1% 0.063W, 1/16W Chip Resistor 0402 (1005 Metric) Moisture Resistant Thick Film | R213, R232 |  | 2 | RC0402N_YAG
 | 10K | Resistor 10 kOhms ±1% 0.063W, 1/16W Chip Resistor 0402 (1005 Metric) Automotive AEC-Q200, Moisture Resistant Metal Film | R215, R219, R223, R226, R227, R233 |  | 6 | RESC1005X40N
 | 4.7K | Resistor, 4.7K Ohms ±1% 0.063W, 1/16W Chip Resistor 0402 (1005 Metric) Moisture Resistant Thick Film | R216 |  | 1 | RC0402N_YAG
 | 20mOhm | Resistor 20 mOhms ±0.5% 1W Chip Resistor 1206 (3216 Metric) Current Sense Metal Film | R217 |  | 1 | RES_PCS1206_3-50mOHM_OHM
 | 8.2K | Resistor 8.2 kOhms ±0.1% 0.063W, 1/16W Chip Resistor 0402 (1005 Metric) Automotive AEC-Q200, Moisture Resistant Metal Film | R218, R220 |  | 2 | RESC1005X40N
 | 18K | Resistor 18 kOhms ±0.1% 0.063W, 1/16W Chip Resistor 0402 (1005 Metric) Automotive AEC-Q200, Moisture Resistant Metal Film | R221 |  | 1 | RESC1005X40N
 | 8.16K | Resistor 8.16 kOhms ±1% 0.063W, 1/16W Chip Resistor 0402 (1005 Metric) Automotive AEC-Q200, Moisture Resistant Metal Film | R224, R237 |  | 2 | RESC1005X40N | KOA Speer | RN73H1ETTP8161F50 | Volume Production | Digikey | 2019-RN73H1ETTP8161F50CT-ND | 0.3
 | 18K | Resistor 18 kOhms ±0.1% 0.063W, 1/16W Chip Resistor 0402 (1005 Metric) Automotive AEC-Q200, Moisture Resistant Metal Film | R225 |  | 1 | RESC1005X40N
 | 30K | Resistor 30 kOhms ±0.1% 0.063W, 1/16W Chip Resistor 0402 (1005 Metric) Automotive AEC-Q200, Moisture Resistant Metal Film | R228 |  | 1 | RESC1005X40N
 | 300K | Resistor 300 kOhms ±0.1% 0.063W, 1/16W Chip Resistor 0402 (1005 Metric) Automotive AEC-Q200, Moisture Resistant Metal Film | R230, R234 |  | 2 | RESC1005X40N | KOA Speer | RN73H1ETTP3003B25 | Volume Production | Digikey | 2019-RN73H1ETTP3003B25CT-ND | 0.32
 | 118K | Resistor 118 kOhms ±0.1% 0.063W, 1/16W Chip Resistor 0402 (1005 Metric) Automotive AEC-Q200, Moisture Resistant Metal Film | R231 |  | 1 | RESC1005X40N | KOA Speer | RN73H1ETTP1183B25 | Volume Production | Digikey | 2019-RN73H1ETTP1183B25CT-ND | 0.16
 | 4.99K | Resistor 4.99 kOhms ±0.1% 0.063W, 1/16W Chip Resistor 0402 (1005 Metric) Automotive AEC-Q200, Moisture Resistant Metal Film | R235 |  | 1 | RESC1005X40N | KOA Speer | RN73H1ETTP4991B25 | Volume Production | Digikey | 2019-RN73H1ETTP4991B25CT-ND | 0.16
 | 5.6K | RES, 330 ±1% 0.063W, 1/16W Chip Resistor 0402 (1005 Metric) Automotive AEC-Q200 Thick Film | R267 |  | 1 | STA_RMCF0402_STP
 | 470 | Resistor,470 Ohms ±1% 0.063W, 1/16W Chip Resistor 0402 (1005 Metric) Thick Film | R272 |  | 1 | RESC1005X35N
 | 120 | Resistor,120 Ohms ±1% 0.063W, 1/16W Chip Resistor 0402 (1005 Metric) Thick Film | R284 |  | 1 | RESC1005X35N
 | 5mΩ 1% 2W | RES 0.005 OHM 1% 2W 2512 | R285 |  | 1 | Resistor 2512 (0.25''x0.125'') | Stackpole Electronics | CSNL2512FT5L00 | Volume Production | Digikey | CSNL2512FT5L00CT-ND | 0.67
 | 90.9K | Resistor, 90.9K Ohms ±1% 0.063W, 1/16W Chip Resistor 0402 (1005 Metric) Moisture Resistant Thick Film | R287 |  | 1 | RC0402N_YAG | Yageo | RC0402FR-0790K9L | Volume Production | Future Electronics | 1290285 | 7
 | RC0603JR-0710KL | RES, 10 k, 5%, 0.1 W, 0603 | R311 |  | 1 | 0603 |  |  |  | Digi-Key
 | 4.02 | Resistor 4.02 Ohms ±1% 1.5W Chip Resistor 2512 (6432 Metric) Automotive AEC-Q200, Pulse Withstanding Thick Film | R331 |  | 1 | RESC6331X70N
 | 20K | Resistor, 10K Ohms ±1% 0.063W, 1/16W Chip Resistor 0402 (1005 Metric) Moisture Resistant Thick Film | R335, R351 |  | 2 | RC0402N_YAG
 | 82K | Resistor, 82 kOhms ±1% 0.063W, 1/16W Chip Resistor 0402 (1005 Metric) Moisture Resistant Thick Film | R339, R355 |  | 2 | RC0402N_YAG
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

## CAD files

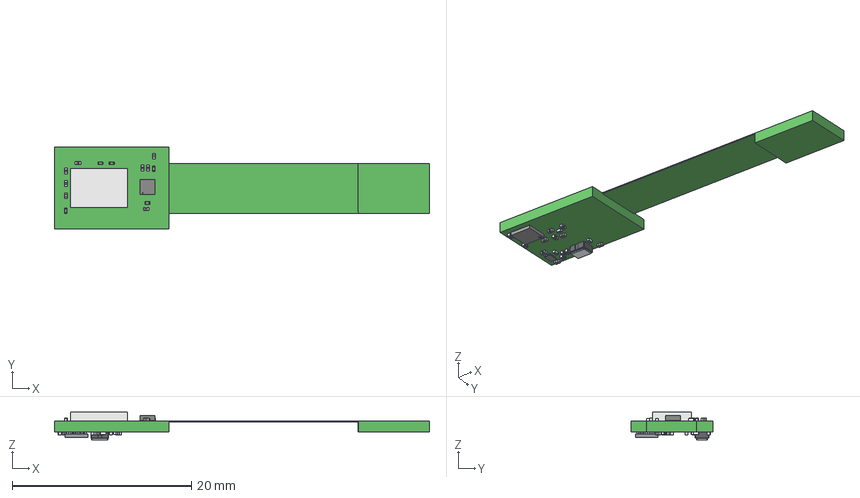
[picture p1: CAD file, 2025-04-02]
Camera Module (700-0303)/3D/7000-0303 Camera Board PCA Rev 2.step
41.8 x 9.09 x 3.11 mm
CRCW0201100KFNED x 8
Extruded
ECS-1633-480-BN-TR

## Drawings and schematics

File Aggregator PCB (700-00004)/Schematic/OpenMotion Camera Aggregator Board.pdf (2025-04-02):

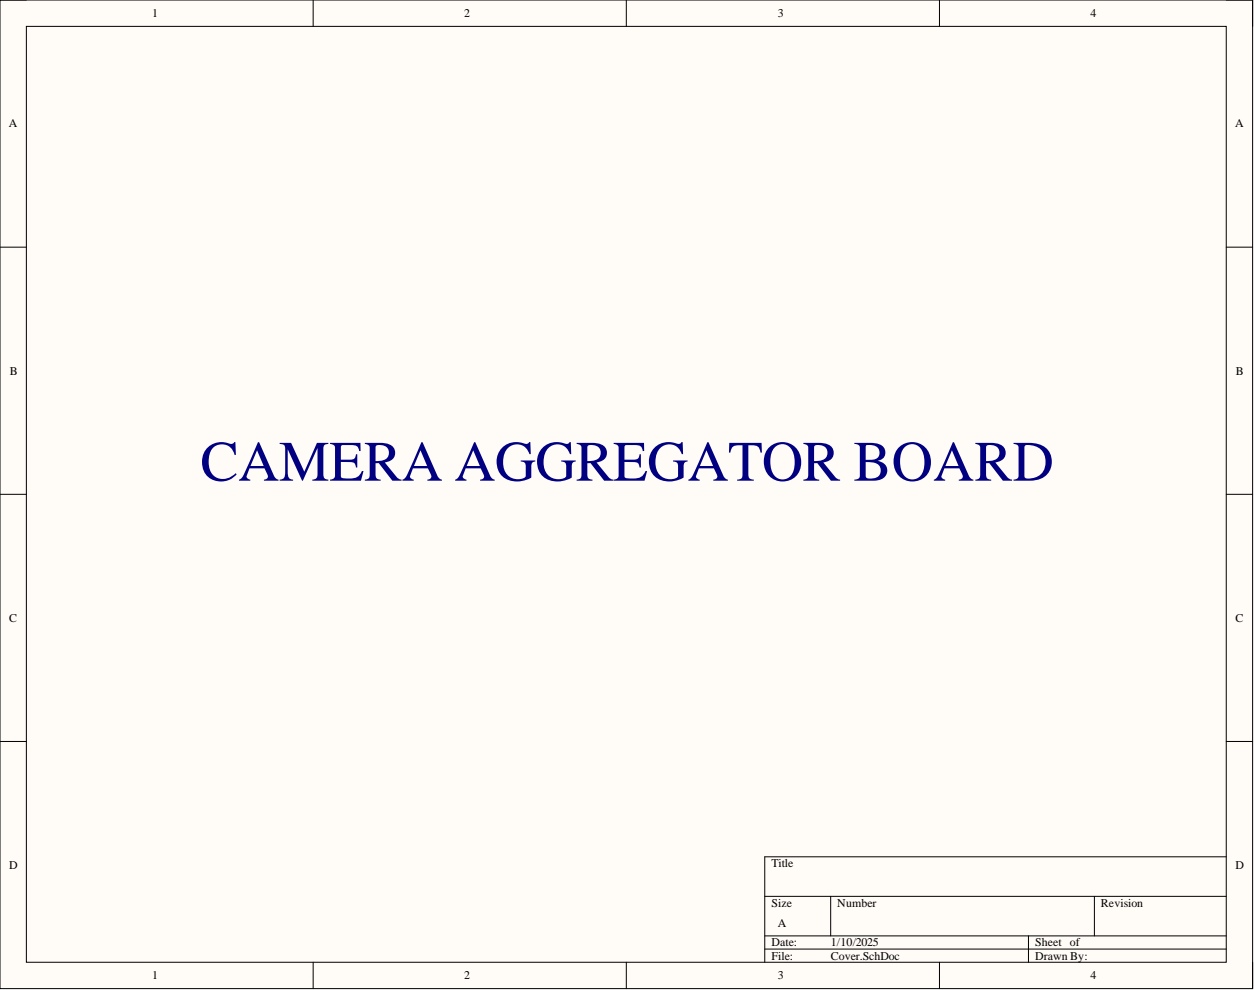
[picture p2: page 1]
Date:; Sheet of; File:; Cover.SchDoc; Drawn By:

CAMERA AGGREGATOR BOARD

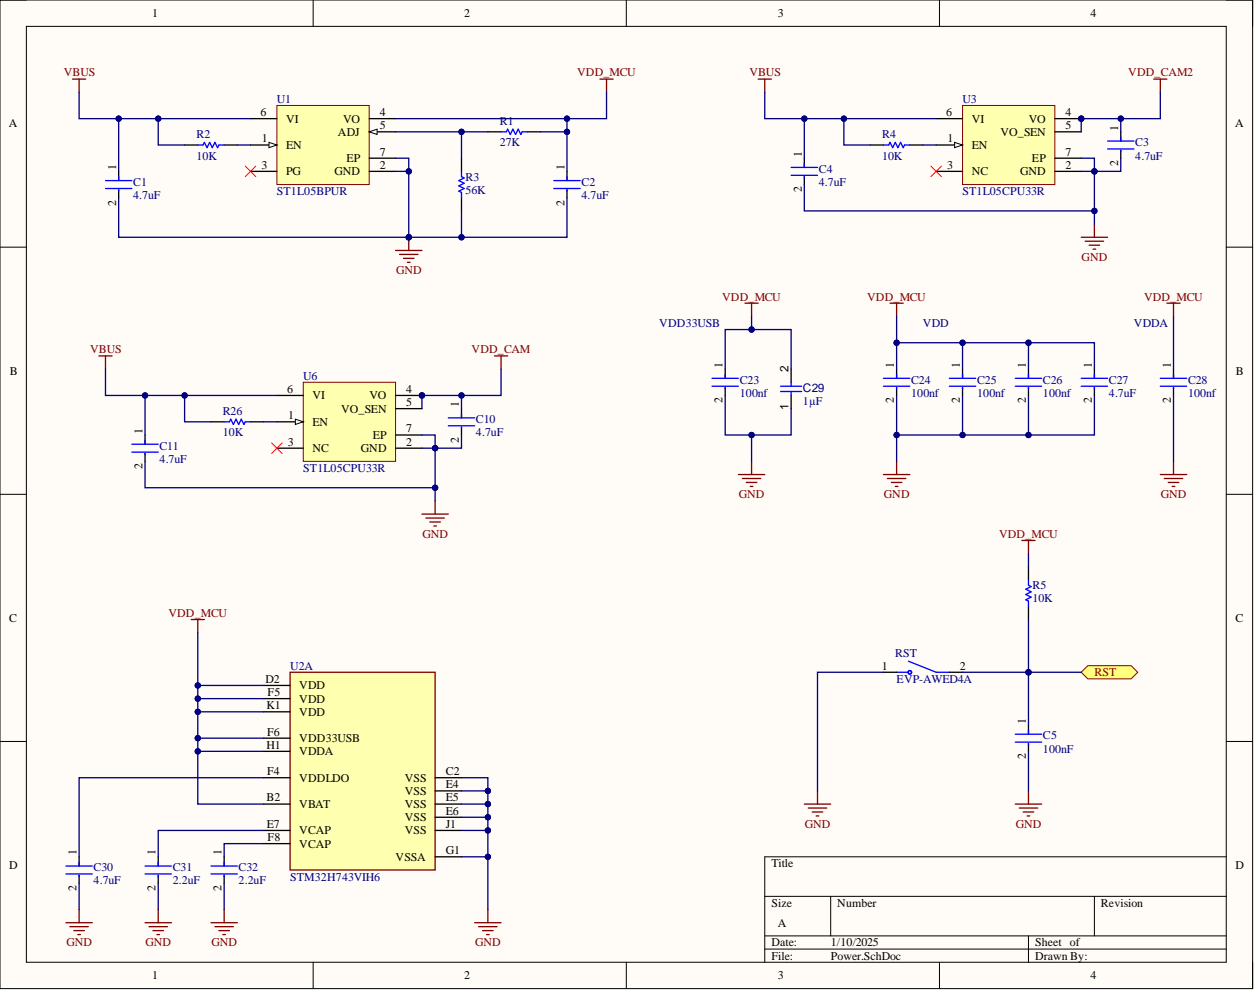
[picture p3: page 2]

VDD F5
VDD K1

VDD33USB F6
VDDA H1

VDDLDO F4

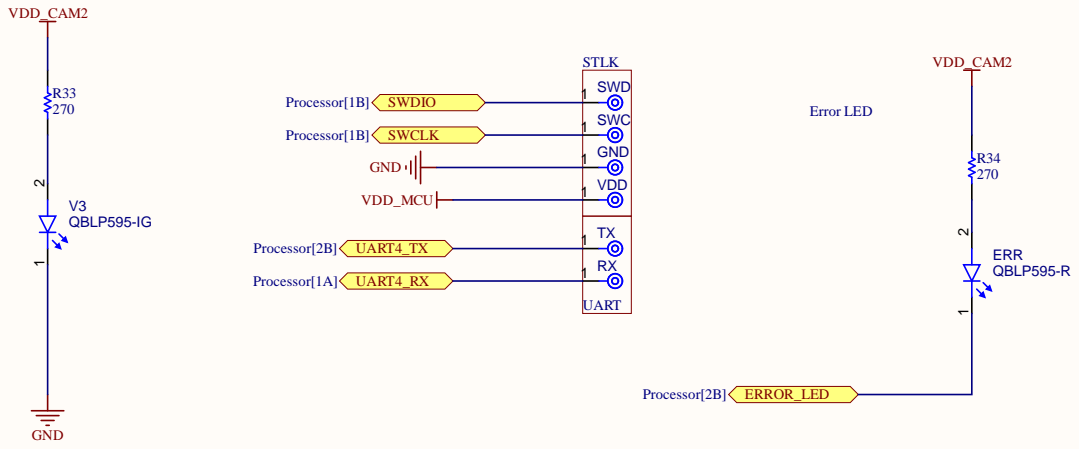
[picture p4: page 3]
D Processor[1B]; SWDIO; PIERR02 COERR; PIR3302 COR33; PIR3402 COR34

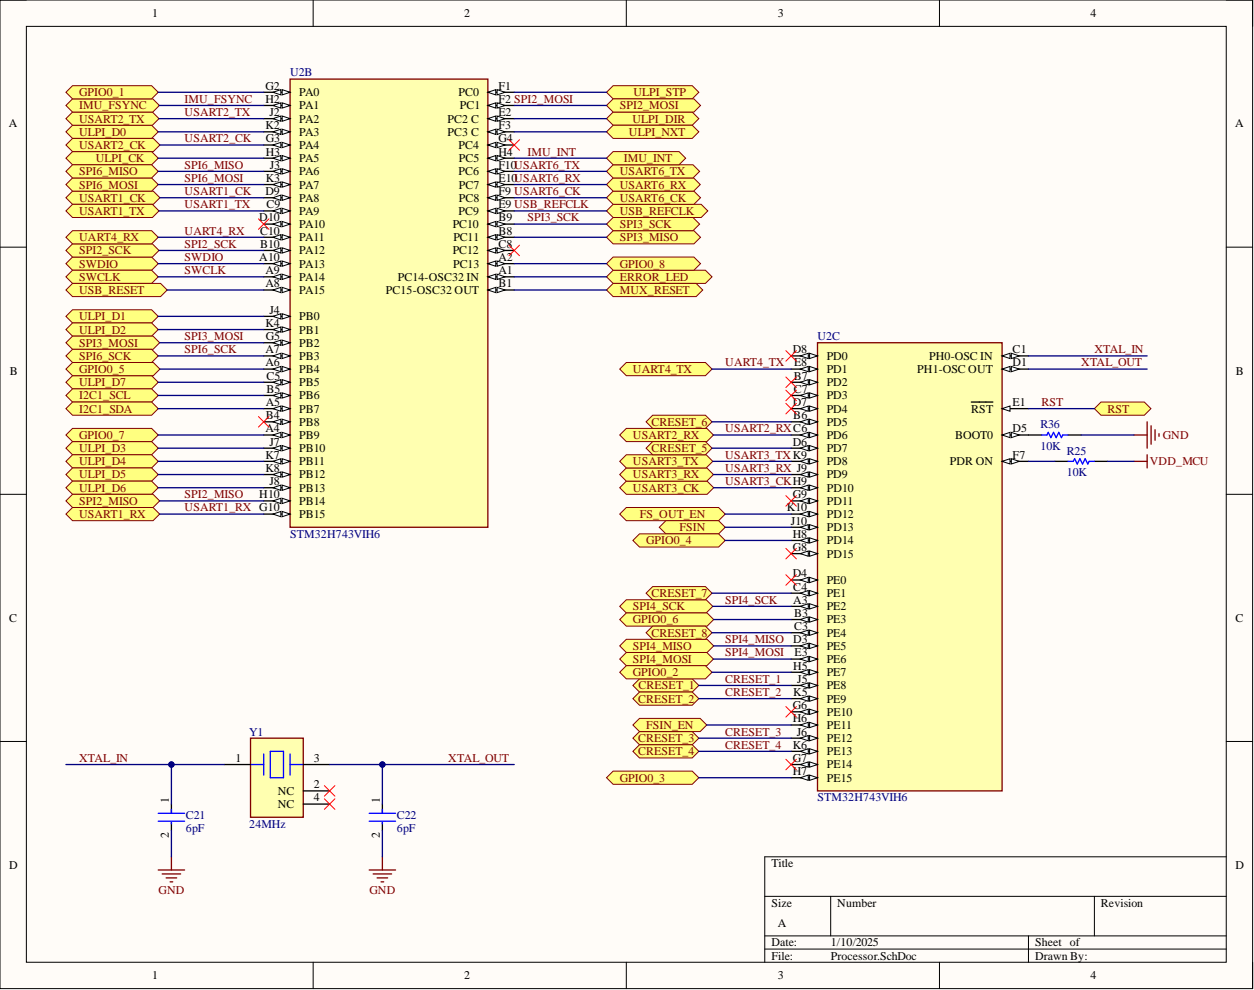
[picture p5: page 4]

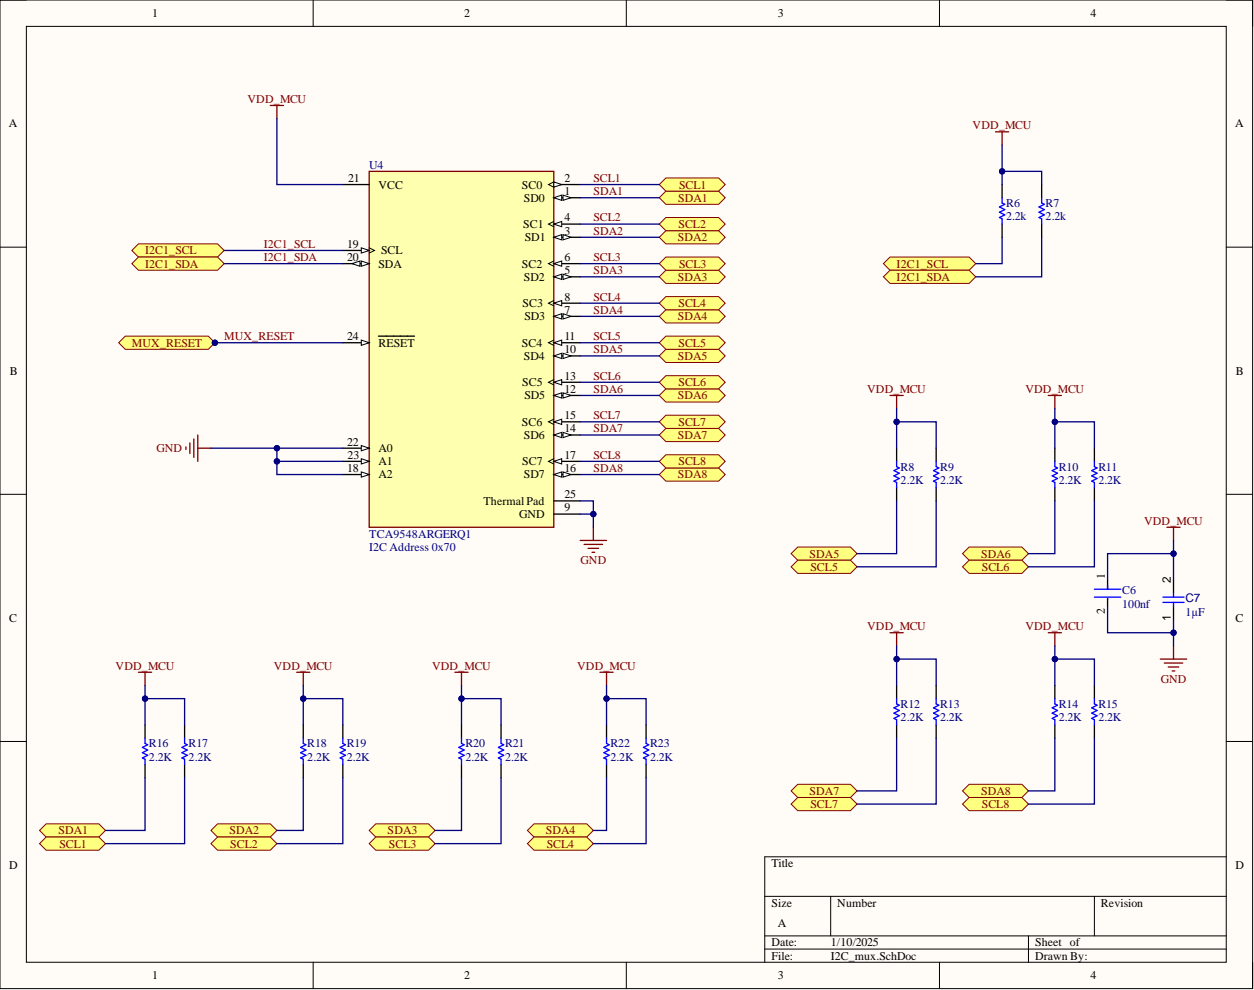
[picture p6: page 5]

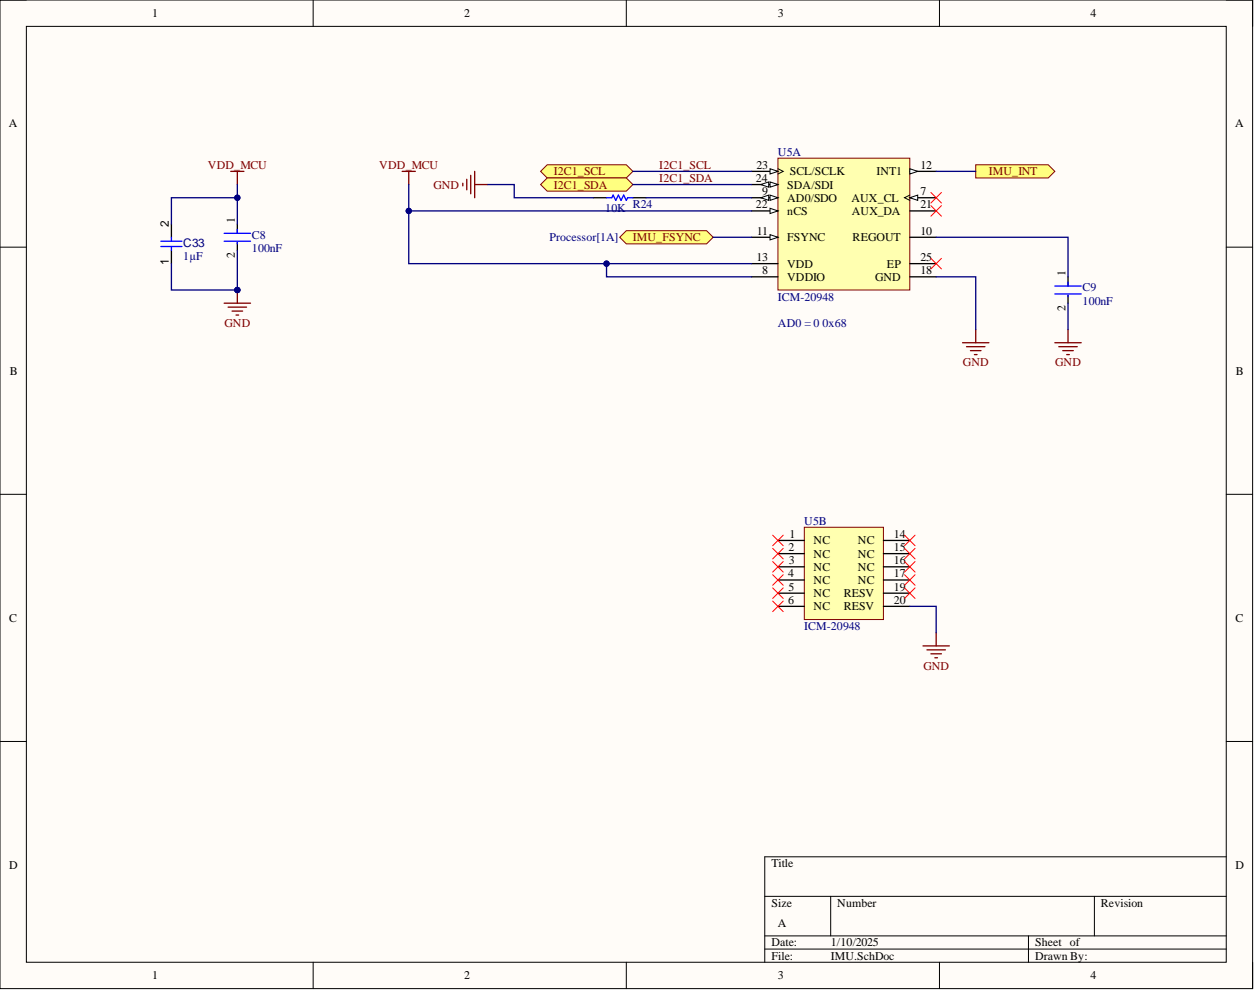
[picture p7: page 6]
File:; IMU.SchDoc; Drawn By:; REGOUT; 10 FSYNC 11; VDD 13; AUX_DA; 21 nCS 22; SCL/SCLK 23 SDA/SDI 24; VDDIO 8; AD0/SDO 9; I2C1_SDA I2C1_SDA

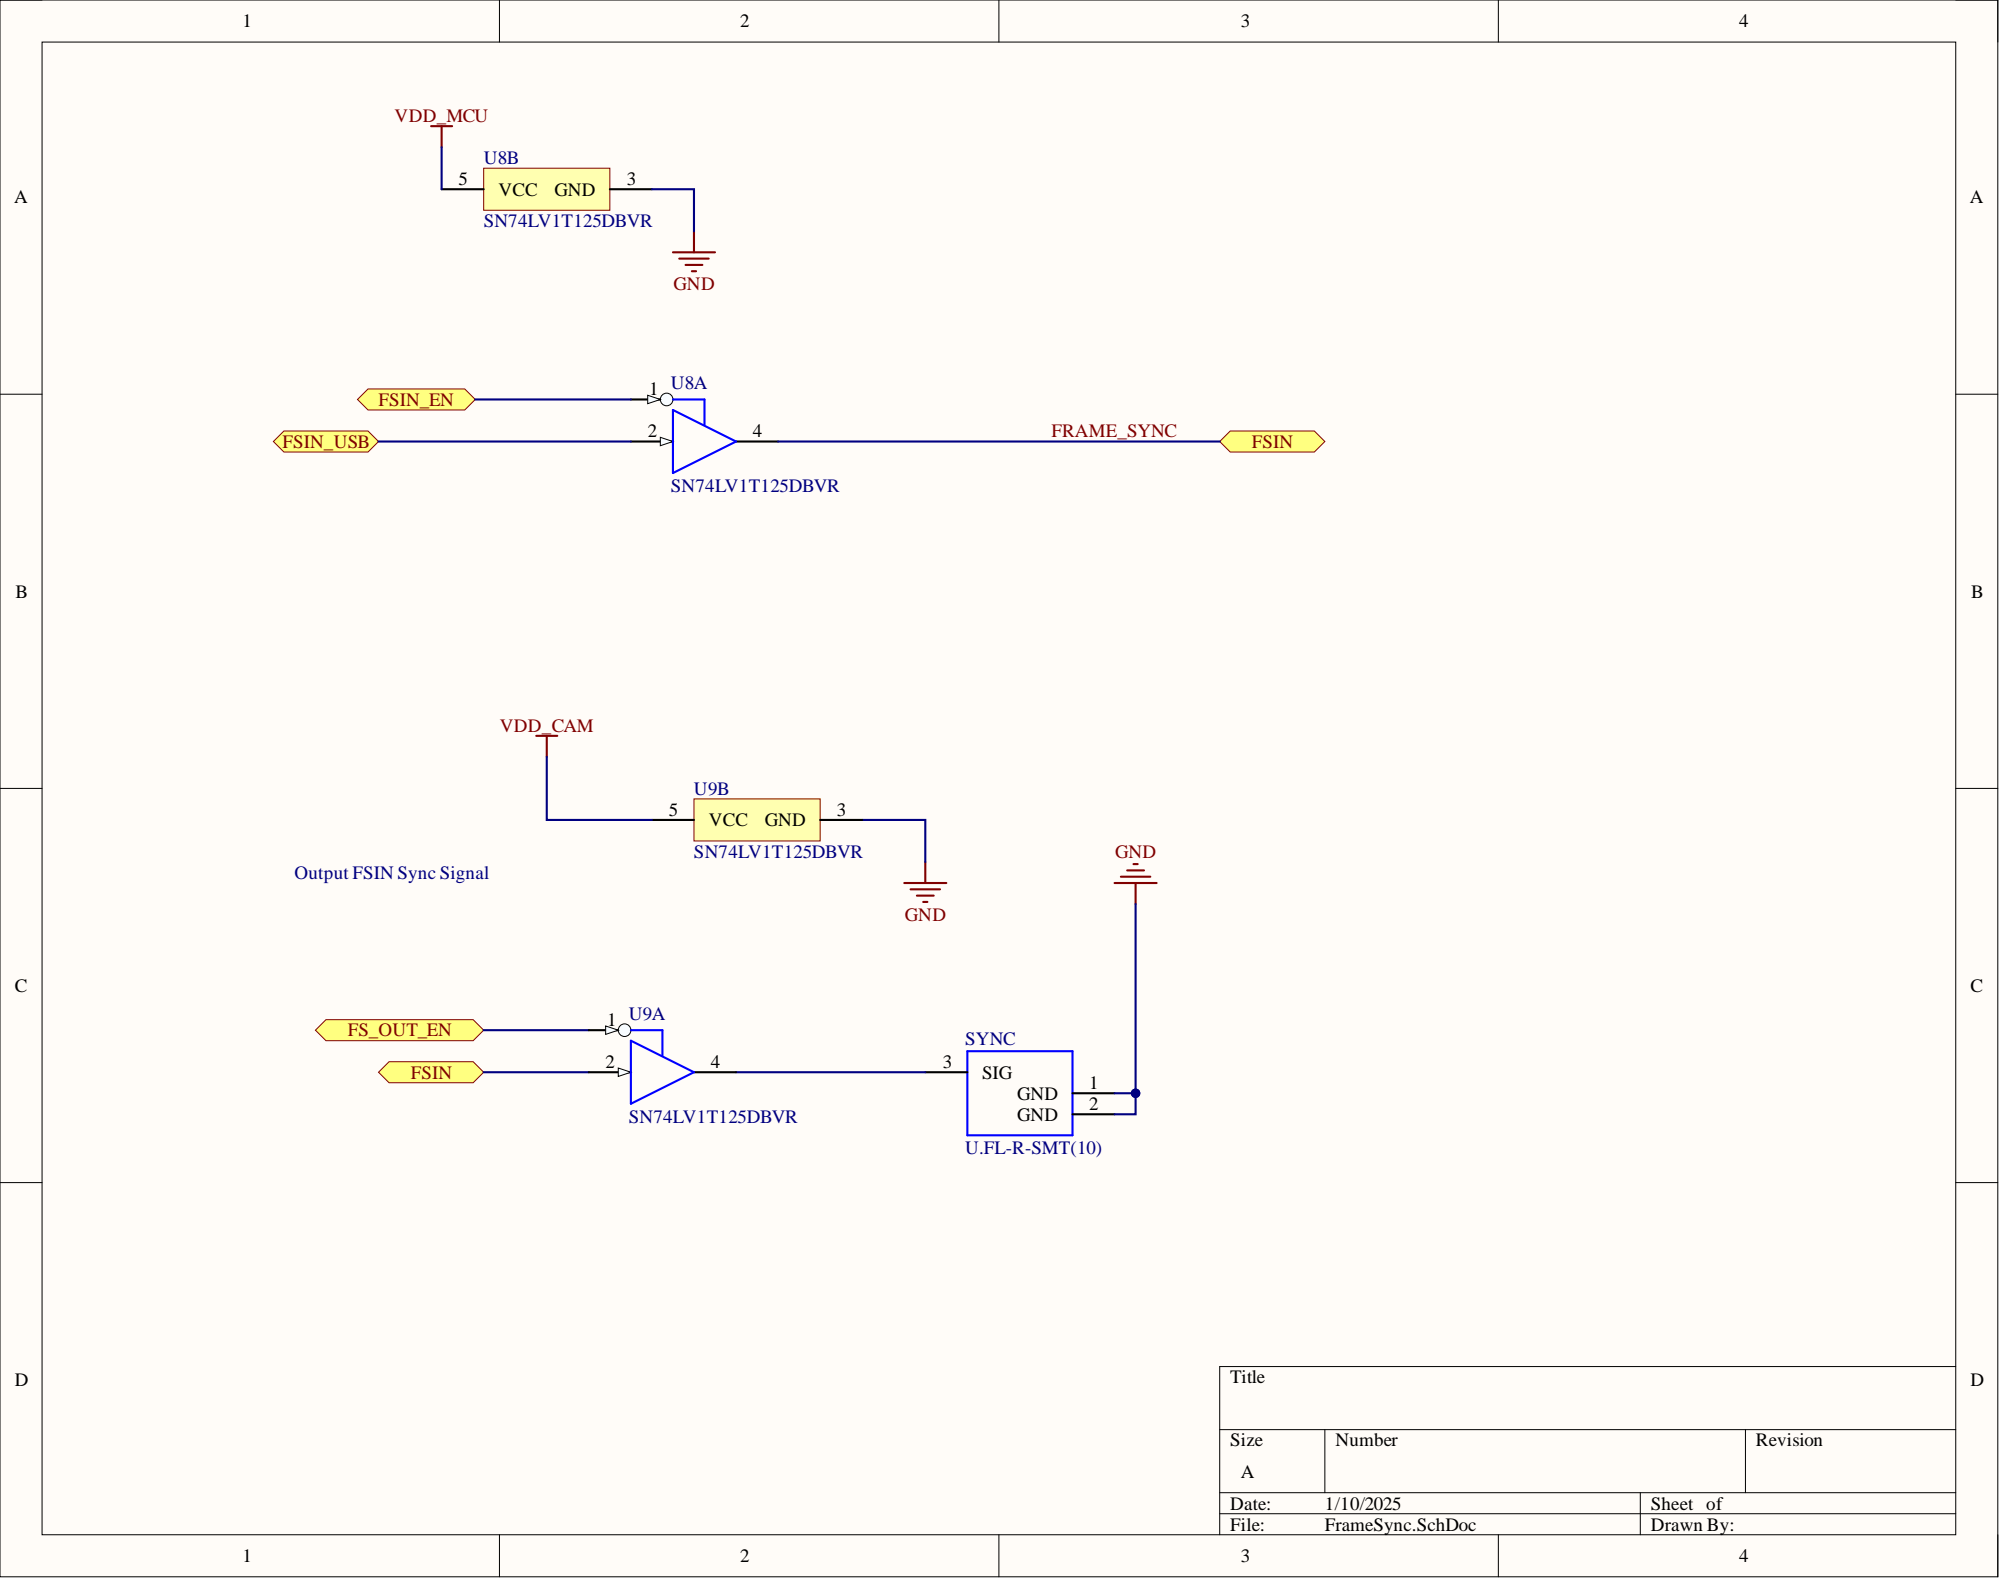
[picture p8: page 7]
File:; FrameSync.SchDoc; Drawn By:; SIG 3; GND; 3 VCC 5

Output FSIN Sync Signal

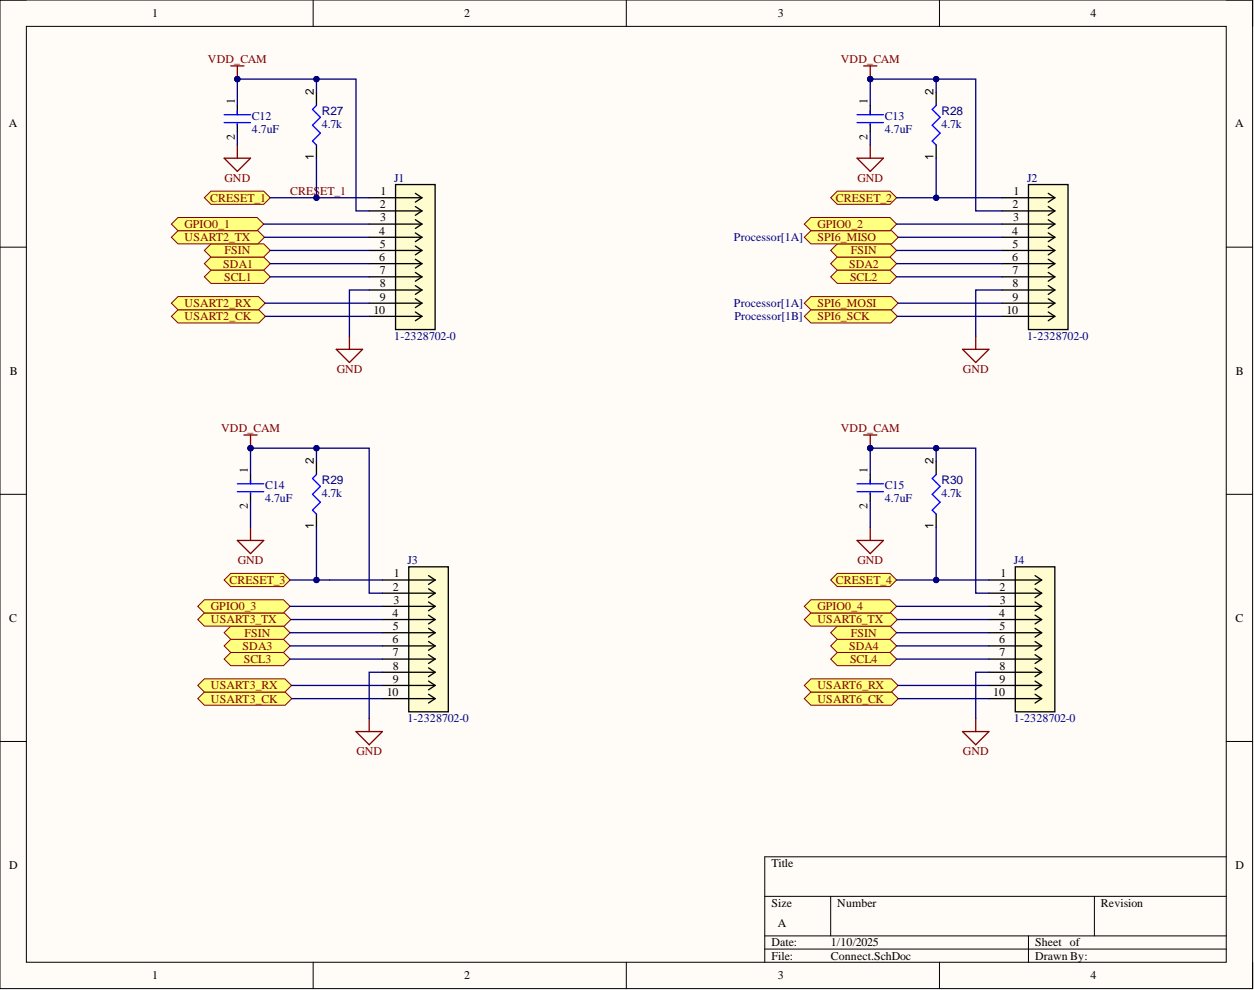
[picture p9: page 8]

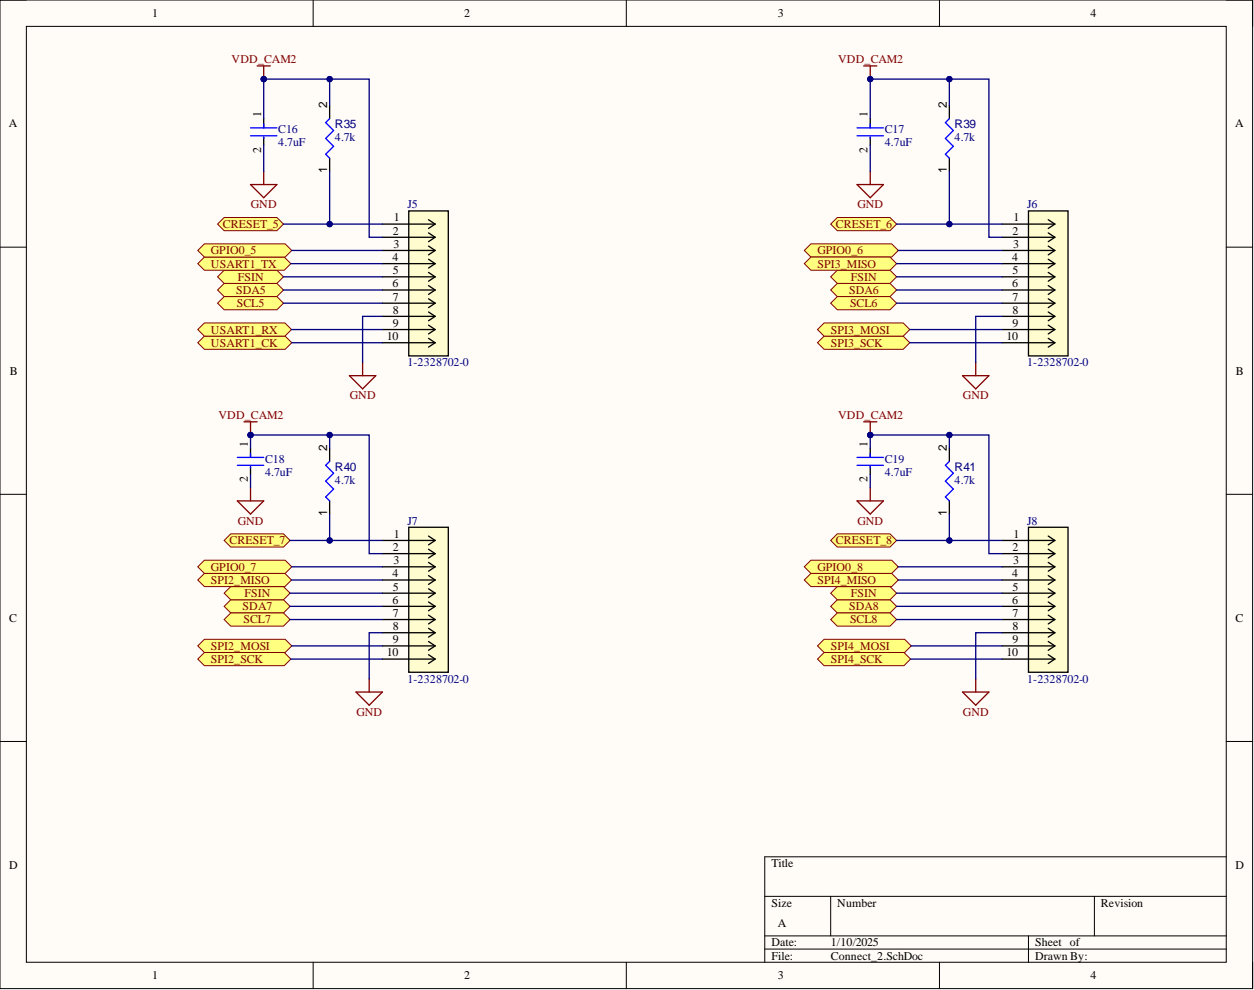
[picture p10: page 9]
FSIN GND

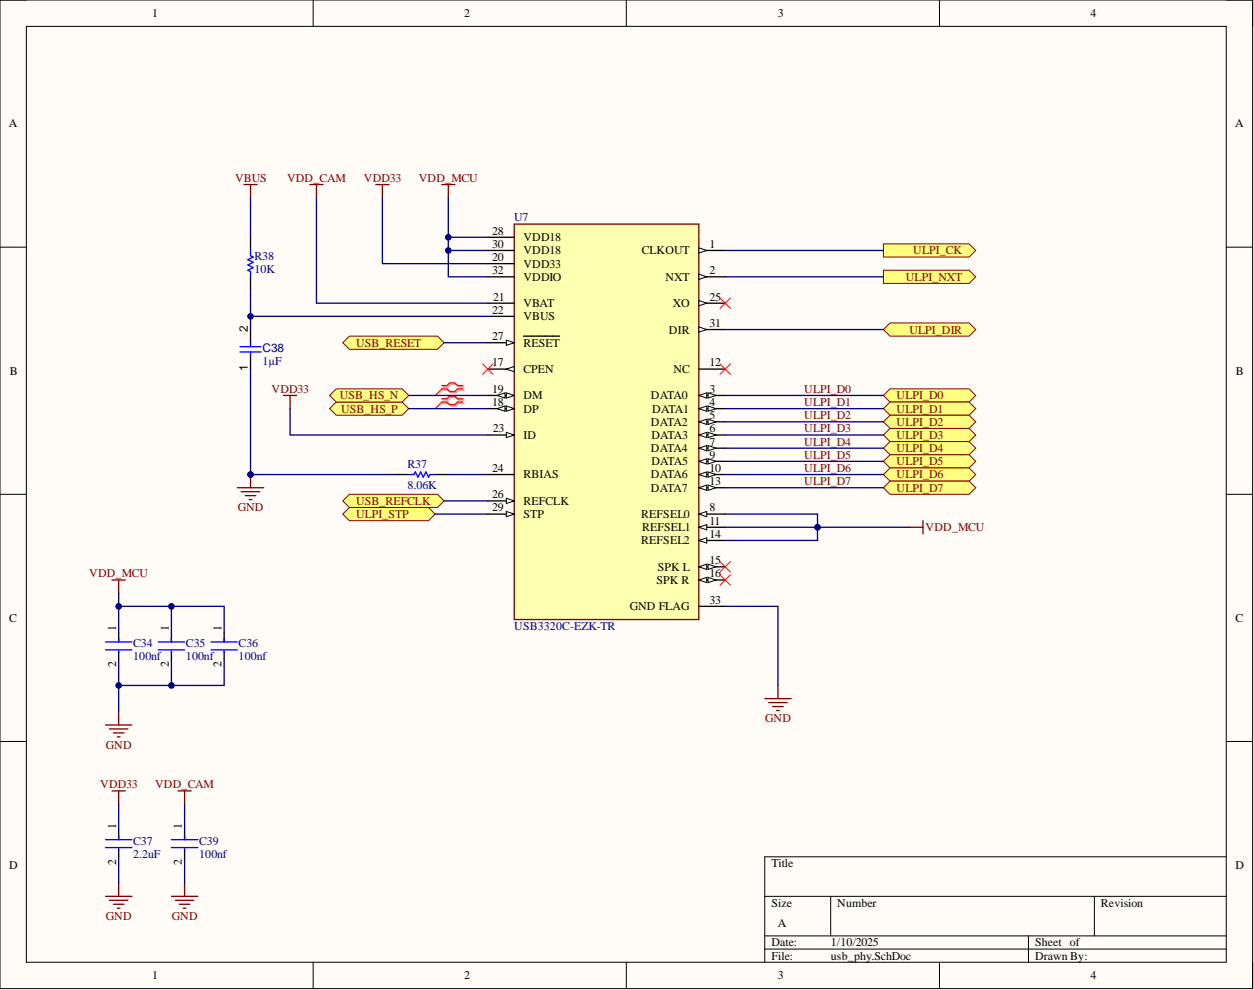
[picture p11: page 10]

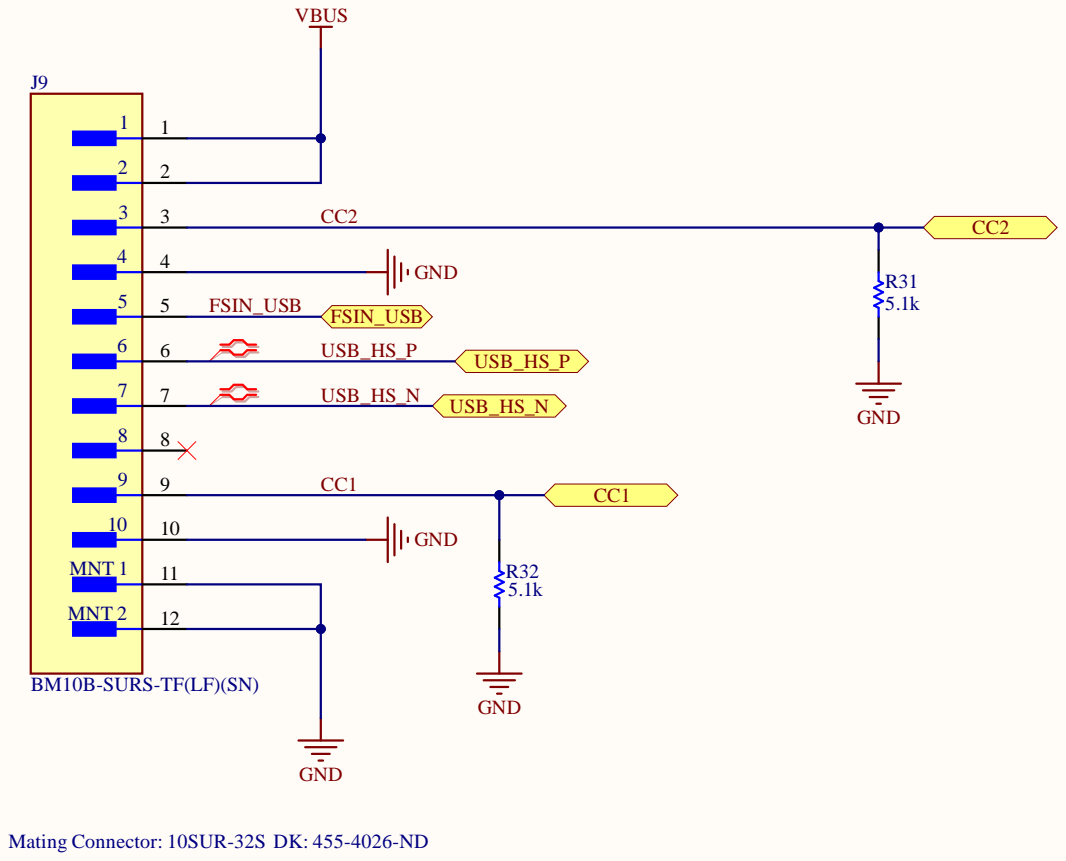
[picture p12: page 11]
File:; USB.SchDoc; Drawn By:; MNT 1; MNT 2; FSIN_USB FSIN_USB

BM10B-SURS-TF(LF)(SN)

Mating Connector: 10SUR-32S DK: 455-4026-ND

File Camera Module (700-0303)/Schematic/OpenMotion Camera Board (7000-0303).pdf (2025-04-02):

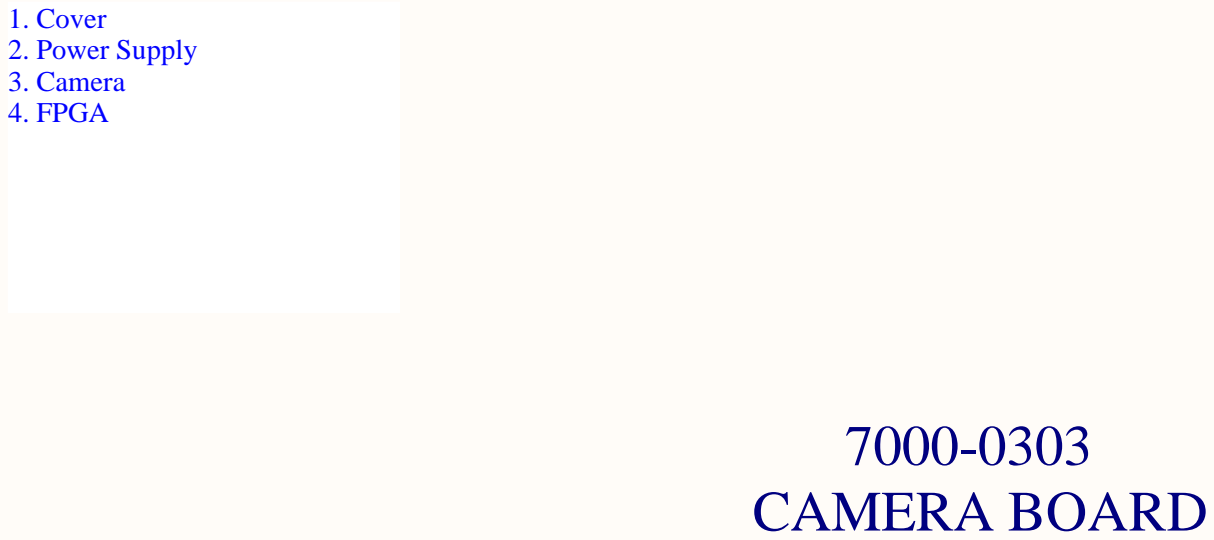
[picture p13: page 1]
Document Number:; Sheet; 1. Cover 2. Power Supply 3. Camera 4. FPGA; CAMERA BOARD; Initial Design; George

Title: Camera Board

Openwater 733 Front Street Suite C1A

Size: B | Item Number: 7000-0303 | Revision: 0

San Francisco, CA 94111, USA
